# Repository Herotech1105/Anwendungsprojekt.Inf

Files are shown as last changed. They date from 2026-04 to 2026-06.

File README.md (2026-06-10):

# Temperatur- und Luftfeuchtigkeitsregulierer

## Anforderungen

* 2 Raspberry Pi 4 B
* 1 Raspberry Pi Pico WH
* Ein Netzwerkkabel mit Internetzugriff
* 2 Micro-SD-Karten
* Netzteile für beide Raspberry Pi 4 B und Aktoren
* Lüfter und Heizung mit passender Leistung
* USB-Kabel mit Micro-USB auf USB-A oder USB-C
* Thonny Software

* Optional für dieses Projekt:
    - Peltier-Element für aktive Kühlung
    - 3D-Druck-Gehäuse
    - Wasserbox für Luftfeuchtigkeit
    - LCD-Display für visuelle Anzeige

## Installation

### Pi Setup

* Installiere das Raspberry Pi OS light Image auf beiden Micro-SDs für die Pis
* Lies die MAC-Addresse eines Pis aus; dieser Pi wird später zum Backend

### WLAN AP

* Verbinde den WLAN Pi über ein Netzwerkkabel mit dem Internet
* Stelle eine Verbindung zum Pi via ssh her
* Setze backend_mac_address in Zeile 4 in `/conficuration/wlan_ap_setup.py` auf die MAC-Addresse des Backends
* Führe `sudo apt install hostapd dnsmasq` auf dem Pi aus
* Kopiere jetzt das Skript `wlan_ap_setup.py` auf den Pi und führe es mit root-Rechten aus

### Pi Pico

* Verbinde den Pi Pico über Micro-USB an USB-A/USB-C eines Endgerätes mit Thonny:
    1. BOOTSEL-Taste (weiße Taste auf Pico) gedrückt halten
    2. An Entwicklungs-Endgerät per USB-Kabel anschließen
    3. .uf2-Datei mit der MicroPython-Firmware auf das Laufwerk "RPI-RP2" per Drag und Drop kopieren.
    4. Pico startet neu
* Danach kann der Pi Pico immer wieder eingesteckt und Thonny geöffnet werden
* Der Pi Pico verbindet sich dann automatisch mit Thonny
* main.py auswählen und "Run current script" Button klicken um zu starten
* Bei Spannungsversorgung ohne Datenfluss (zum Beispiel Pico direkt über USB-Kabel an Netzteil) startet main.py
  automatisch

### Backend server

* Verbinde dich über ssh mit dem Backend
* Verbinde dich mit `nmtui` mit dem WiFi:
    1. Führe `nmtui` aus
    2. Wähle "Activate a connection"
    3. Wähle das Netzwerk aus und gebe das Passwort ein (Standard: Production, Production-01)
* Klone das Repository auf das Backend
* Installiere Docker Compose
* Zum Starten der Software führe jetzt `sudo docker compose up` im Projektverzeichnis aus

## Bedienung

Die Applikation lässt sich mit `sudo docker compose up/down` starten und beenden.  
Vor dem Start ist sicherzustellen, dass der WLAN-AP Pi hochgefahren und funktionstüchtig ist (z.B. indem geprüft wird,
ob das Backend ´mit dem zugehörigen WLAN verbunden ist).  
Der Pico wird durch Ausführen der `main.py` gestartet.
Nach dem Start kann eine Verbindung zum Netzwerk aufgebaut werden und
unter [https://local.kleber.data](https://local.kleber.data) das Web Dashboard besucht werden.  
Hier folgt eine Anmeldung mit [iotuser01]: [password] oder [admin]: [admin].  
Danach wird das Dashboard angezeigt.
Als Admin besteht außerdem die Möglichkeit alle Sensordaten als CSV-Datei zu exportieren.

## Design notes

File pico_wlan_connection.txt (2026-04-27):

>>> %Run -c $EDITOR_CONTENT

MPY: soft reboot
Verbinde mit WLAN...
...
...
...
Verbunden! IP: 192.168.4.20
Hole Außentemperatur von Open-Meteo...
Außentemperatur Friedrichshafen: 18.9 °C

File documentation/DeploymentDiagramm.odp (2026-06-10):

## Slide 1

Internet

WLAN-Router (Raspberry Pi 4B)

Sensoren

Actoren

Client-User

Raspberry Pico W

HTTPS:TLS: 8883

Moskito PUB

BackendServer (Raspberry Pi 4B)

App-net

SUB

HTTPS:443

Sensor-net

HTTPS:

8443

keyCloak

(AuthN/AuthZ))

HTTPS:3000

keyCloak

(AuthN/AuthZ)

HTTPS:

8443

MariaDB

(Database)

Mosquitto

SUB

Controller.py

HTTPS:443

Nginx mit Modsecure

Webapp/

(server.js)

SQL & TLS :3306

PUB

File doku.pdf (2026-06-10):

## Temperatur- und Luftfeuchtigkeitsregulierer

In diesem Projekt wurde ein Regulierungssystem für Luftfeuchtigkeit und Temperatur entwickelt, dass die Messdaten sicher
speichert und für einen authentifizierten Nutzer die Messdaten der letzten Woche visualisiert. Zielwerte für die Temperatur sind zwischen 19 °C und 21 °C und für die Luftfeuchtigkeit zwischen 40 % und 55 %.

Das Projekt wurde bewältigt durch:

- Tim Dorozynski
- Lennart Esch
- Benjamin Hager
- Walter Neer
- Barnabas Steiner
- Jannis Weber

# Inhaltsverzeichnis

## Anforderungen und Struktur

Die Anforderungen für das Endprodukt waren die folgenden:

Funktionale Anforderungen:

Nr. | Funktion | Beschreibung | Prio
FA1 | Sensormessung | Das System misst regelmäßig (z. B. alle 60 s) Temperatur und Luftfeuchtigkeit an der Klebestation. | Must
FA2 | Datenübertragung | Messwerte werden vom Mikrocontroller sicher über WLAN/MQTT an den Backend-Server übertragen. | Must
FA3 | Automatische Temperatursteuerung | Temperatur wird automatisch im Bereich 19–21 °C gehalten (Aktor: Heizung/Lüfter, Regelung per LSTM). | Must
FA4 | Automatische Feuchtigkeitssteuerung | Luftfeuchtigkeit wird automatisch im Bereich 40–55 % gehalten. | Must
FA5 | Web-Dashboard (Visualisierung) | Mitarbeiter sehen den zeitlichen Verlauf von Temperatur und Luftfeuchtigkeit grafisch im Leitstand. | Must
FA6 | Manueller Eingriff | Bei Ausfall der automatischen Steuerung können Mitarbeiter manuell über das Dashboard Aktoren steuern. | Must
FA7 | Datenspeicherung Kurzzeit | Sensordaten werden für mindestens 7 Tage online in einer Datenbank abrufbar gespeichert. | Should
FA8 | Datenspeicherung Langzeit | Ältere Daten werden für mindestens 3 Jahre archiviert und können bei Bedarf wieder eingespielt werden. | Should

Nicht-funktionale Anforderungen:

Nr. | Anforderung | Beschreibung | Prio
NFA1 | Sicherheit – Verschlüsselung | Alle Sensor- und Steuerungsdaten werden verschlüsselt (TLS) übertragen. | Must
NFA2 | Authentifizierung & Autorisierung | Zugriff auf das Web-Dashboard nur mit gültigem Benutzerkonto und Passwort (z. B. Keycloak/IAM). | Must
NFA3 | Netzwerkisolation | Das WLAN der Klebestation ist durch eine Firewall vom Unternehmens-LAN getrennt; eingehender Verkehr wird blockiert. | Must
NFA4 | Verfügbarkeit / Zuverlässigkeit | Bei Ausfall der automatischen Steuerung muss manueller Eingriff weiterhin möglich sein (kein Single Point of Failure). | Must
NFA5 | Kosteneffizienz | Gesamtkosten für Hardware und Software unter 10.000 €; Software soll Open Source sein. | Must
NFA6 | Wartbarkeit | Betrieb mit standardisierten Docker-Containern für einfache Updates und Wartung. | Should
NFA7 | Mobilität / WLAN | Kommunikation über WLAN, da die Klebestation häufig räumlich verschoben wird und Kabel nicht praktikabel sind. | Must
NFA8 | Datenschutz (DSGVO) | Sensordaten sind keine personenbezogenen Daten — datenschutzrechtlich unkritisch, Compliance dennoch prüfen. | Should
NFA9 | Benutzbarkeit | Das Dashboard muss für Leitstandmitarbeiter ohne IT-Kenntnisse intuitiv bedienbar sein. | Could

Zur Erarbeitung des
Projekts wurde dieses in die folgenden 6 Phasen eingeteilt:
1. Planung und Einteilung der folgenden Phasen
2. Erstellen eines WLAN Access Points mit Firewall
3. Verdrahtung des Pico und Übertragen der Sensordaten an das Backend
4. Sicheres Speichern der Sensordaten in der Datenbank
5. Steuerung der Aktoren des Pico mittels LSTM-Netz
6. Erstellen einer sicheren Webapplikation für die Sensordaten

## Phasen (patchnotes)

Die Präsentationen zu den einzelnen Phasen sind als PDF im jeweiligen Verzeichnis zu finden.
Im Folgenden sind die konkreten Änderungen während der einzelnen Phasen aufgegliedert:

## Phase 1:

Datum: 11.04.2026 - 23.04.2026
Problemstellung: Planung des Projektes und dessen 6 Phasen Verantwortlicher: Jannis Weber
Projektplan:

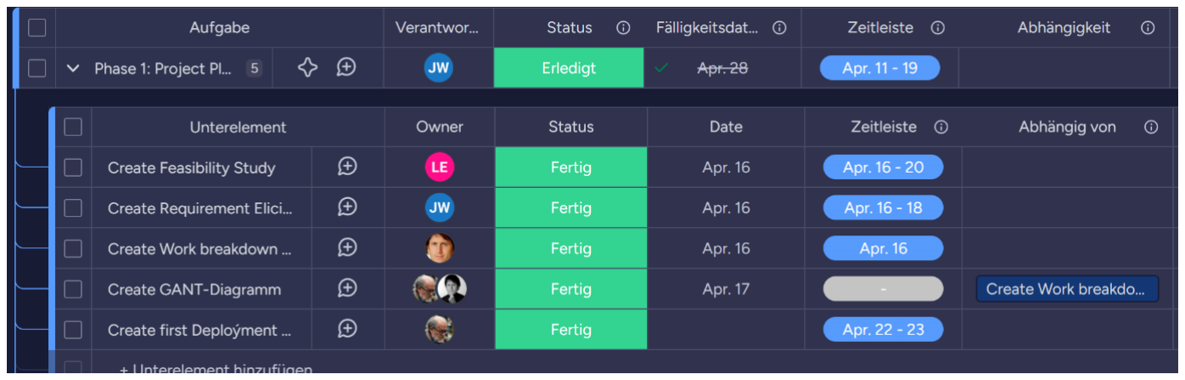
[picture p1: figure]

Datei | Änderung | Erklärung
AnwendungInfoEli.pdf | N/A | Beschreibung der Anwendung und Projektidee mit Zielsetzung und Rahmenbedingungen
Machbarkeitstudie1.pdf | N/A | Machbarkeitsstudie zur technischen und wirtschaftlichen Umsetzbarkeit des Projektes
6Phasen.png | N/A | Erstmalige Verteilung der ersten Phasen

Machbarkeitsstudie:

Technik | Gegenstand der Bewertung | Bewertung
Technische Machbarkeit | Personal und Fachkompetenz; Hardware; Software | Vorkenntnisse in Web-Entwicklung und teilweise Elektrotechnik vorhanden; Hardware bereits gestellt; ausschließlich Open-Source-Software verwendbar
Wirtschaftliche Machbarkeit | Investitionskosten; Entwicklungskosten; Wartungskosten; Betriebskosten | Hardware bereits gestellt; kostenlose Software, keine Personalkosten; Betriebskosten beschränken sich auf Stromverbrauch und möglichen Hardware-Verschleiß
Organisatorisc he Machbarkeit | Integration in bestehende Systeme; Fachkenntnisse für Betrieb | Keine bestehende Systemlandschaft, keine Integration notwendig; Betrieb erfordert keine spezifischen Fachkenntnisse nach Demonstration
Zeitliche Machbarkeit | Zeit für Kompetenzgewinn; Zeit für Entwicklungsarbeit | Benötigte Kompetenzen können im Zeitrahmen erworben werden; ab dem 28.04.2026 ist die verfügbare Entwicklungszeit ausreichend
Rechtliche Machbarkeit | Personenbezogene Daten; Schutz erhobener Daten | Keine personenbezogenen Daten erhoben; Daten können durch Security-By-Design geschützt werden
Risiken und Gegenmaßnah men | Frühere Abgabe; Verzug durch langsame Arbeit oder größeren Zeitaufwand bei Kompetenzaneignung | Risiko gering; Verzug wahrscheinlich, Gegenmaßnahme: Überstunden

Machbarkeitsbericht: Das Projekt wird unter den oben angegebenen Umständen als durchführbar eingestuft.

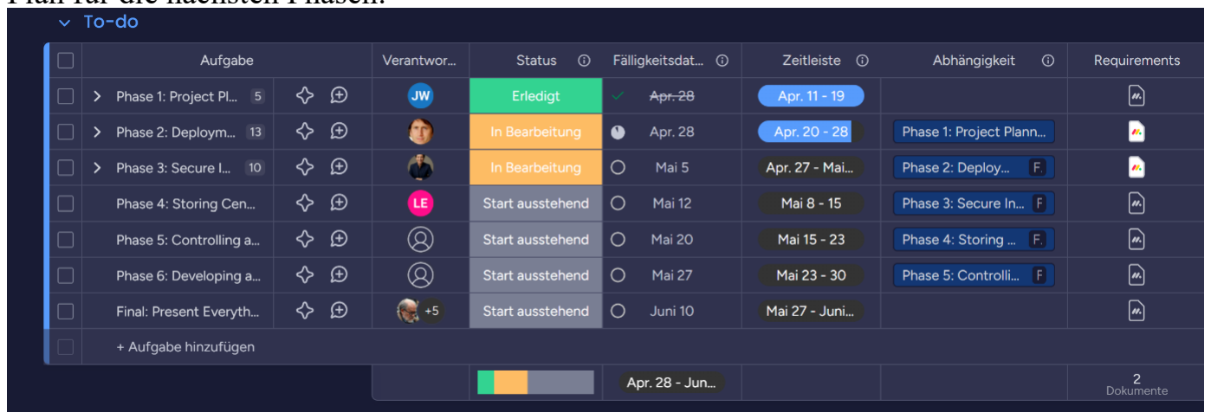
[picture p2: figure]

Plan für die nächsten Phasen:

## Phase 2:

Datum: 11.04.2026 - 28.04.2026
Problemstellung: Deployment der Kern-Infrastruktur Verantwortlicher: Benjamin Hager
GANT-Diagramm:

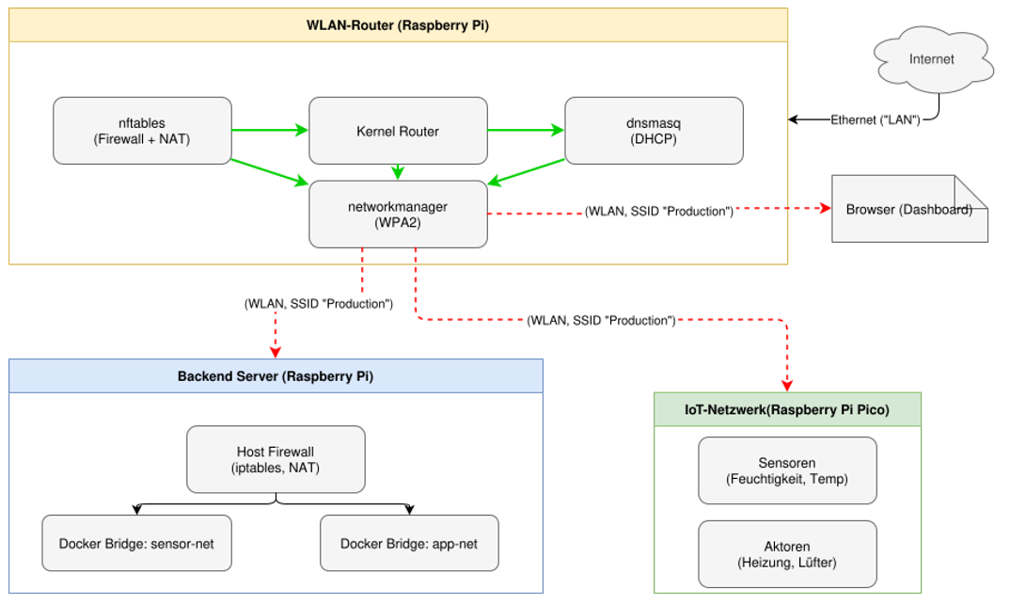
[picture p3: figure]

Deployment-Diagramm:

Datei | Änderung | Erklärung
configuration s/wlan_ap_set up.py | Neu erstellt, danach mehrfach überarbeitet (Firewall-Regeln korrigiert, SSH auf allen Interfaces erlaubt, Quellen ergänzt) | Python-Skript zur Einrichtung eines WLAN-Access-Points auf dem Raspberry Pi: konfiguriert hostapd, dnsmasq, statische IP (192.168.4.1), IP-Forwarding und nftables-Firewall mit NAT (Masquerading über eth0). Ermöglicht das Produktionsnetzwerk "Production" für IoT-Clients.
configuration s/pico_main.p y | Neu erstellt, danach erweitert (Phase 2 Integration) | MicroPython-Skript für den Raspberry Pi Pico W: verbindet sich als WLAN-Client mit dem Produktionsnetzwerk, ruft die Außentemperatur aus Friedrichshafen via Open-Meteo-API ab und steuert die Onboard-LED (Blinkrate abhängig von Temperatur: <10°C → 2s, ≤25°C → 1s, >25°C → 0.3s).
pico_wlan_co nnection.txt | Neu erstellt, danach angepasst | Dokumentation/Notizen zur WLAN-Konfiguration des Pico W (SSID, Passwort, Verbindungsaufbau).

## Phase 3:

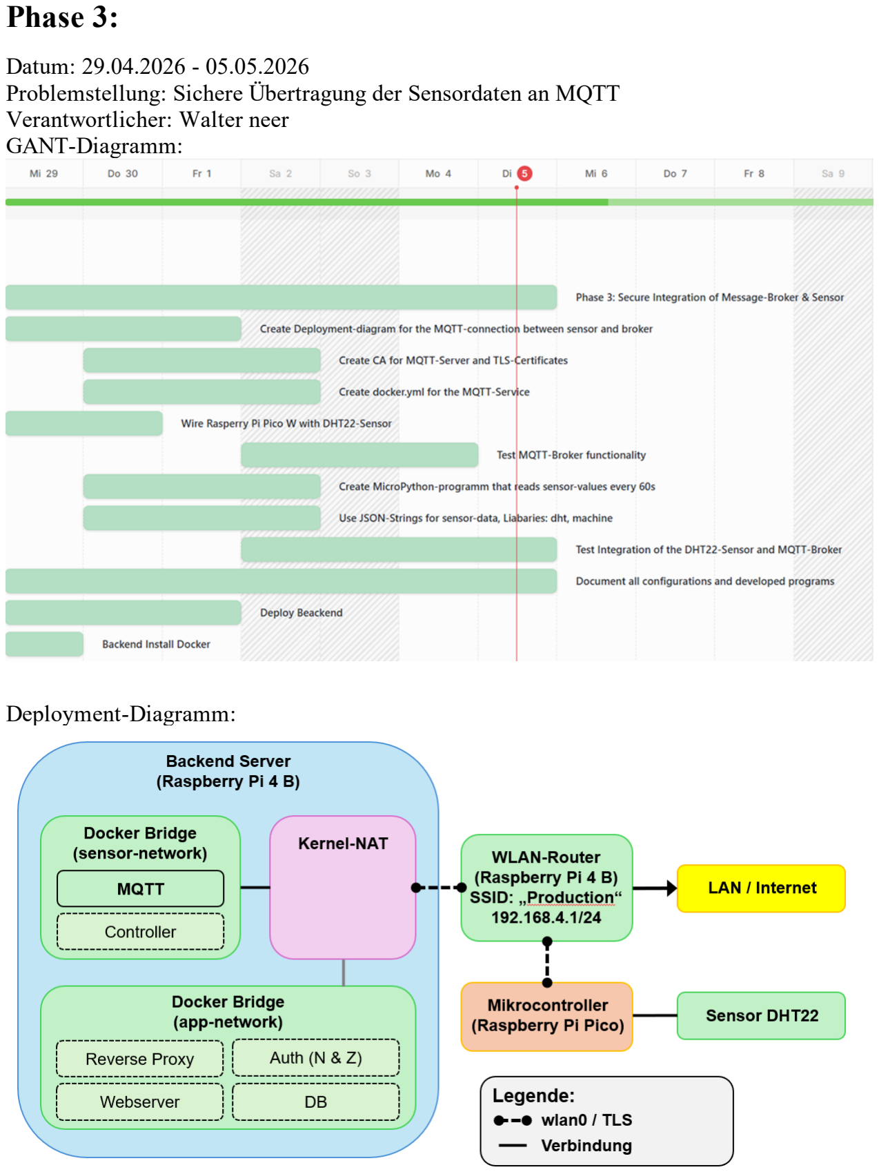
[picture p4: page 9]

Datum: 29.04.2026 - 05.05.2026
Problemstellung: Sichere Übertragung der Sensordaten an MQTT Verantwortlicher: Walter neer
GANT-Diagramm:

Deployment-Diagramm:

Datei | Änderung | Erklärung
configurations/pico _main.py | In Module aufgeteilt | Aufgrund von Erweiterungen des Codes, für die Übersichtlichkeit in Module mit eigener Zuständigkeit aufgeteilt
configurations/pico/ iot_config.py | Neu | Enthält alle Variablen für die Konfiguration von MQTT, CA und WLAN
configurations/pico/ control.py | Neu | Initialisierung der Pico Pins und Zuweisung an Sensor und Aktoren
configurations/pico/ wifi.py | Neu | Zuständig für Konfiguration und Aufbau einer WLAN-Verbindung
configurations/pico/ mqtt.py | Neu | Zuständig für Konfiguration, Verarbeitung und Aufbau einer MQTT-Verbindung mit CA
configurations/pico/ states.py | Neu | Steuert Aktoren je nach erhaltener Anweisung mit Zustandsinformation
configurations/pico/ main.py | Neu | Hauptdatei des Pico, wird als erstes ausgeführt und ist für den Programmablauf verantwortlich
configurations/pico/ lib/picozero | Schon in Phase 2 enthalten | Bibliothek für die Ansteuerung der On-Board-LED des Pico
configurations/pico/ lib/umqtt | Neu | Bibliothek für MQTT relevante Funktionen, enthält simple.py und robust.py
configurations/pico/ lib/lcd_api.py | Neu | Basisklasse für den Aufbau einer I2C-Verbindung
configurations/pico/ lib/pico_i2c_lcd.py | Neu | Enthält Methoden für das Ansteuern eines LCD-Displays über den Pico, verwendet die Basisklasse aus lcd_api.py
CA/ca.key | Neu | Private Schlüsseldatei der CA, zum Signieren von Zertifikaten
CA/ca.srl | Neu | Seriennummerndatei der CA, enthält Seriennummern von signierten Zertifikaten
CA/ca.crt | Neu | Öffentliches Zertifikat der CA, zum Prüfen der Signatur anderer Zertifikate
CA/ca.der | Neu | Wie ca.crt aber als Binärdatei statt Text, damit der Pico damit arbeiten kann
CA/req.cnf | Neu | Konfigurationsdatei für OpenSSL mit Einstellungen für beispielsweise

Datei | Änderung | Erklärung
| | Erweiterungen (weitere Hostnamen), wird für mqtt.csr und ca.crt verwendet
CA/mqtt.key | Neu | Privater Schlüssel des MQTT-Servers, wird für TLS-Verschlüsselung benutzt
CA/mqtt.csr | Neu | Wird aus mqtt.key erzeugt, für das Erhalten eines Zertifikats vom CA
CA/mqtt.crt | Neu | Signiertes Zertifikat des MQTT-Brokers, vom ca.key signiert, Beweis für Clients, dass das Zertifikat über CA gültig ist
docker-compose.yml | Neu, Konfiguration für mqtt-Container hinzugefügt | Konfiguration mit eclipse-mosquitto Image und Port 8883, benötigte volumes gemountet
mosquitto/config/m osquitto.conf | Neu | Konfigurationsdatei für den MQTT-Broker
mosquitto/log/mosq uitto.log | Neu | Logdatei für den MQTT-Broker
mosquitto/secure/ac l | Neu | Angelegte Nutzer und deren Zugriffsrechte auf topics
mosquitto/secure/p wfile | Neu | Existierende Nutzer und deren verschlüsselte Zugangsdaten

## Phase 4:

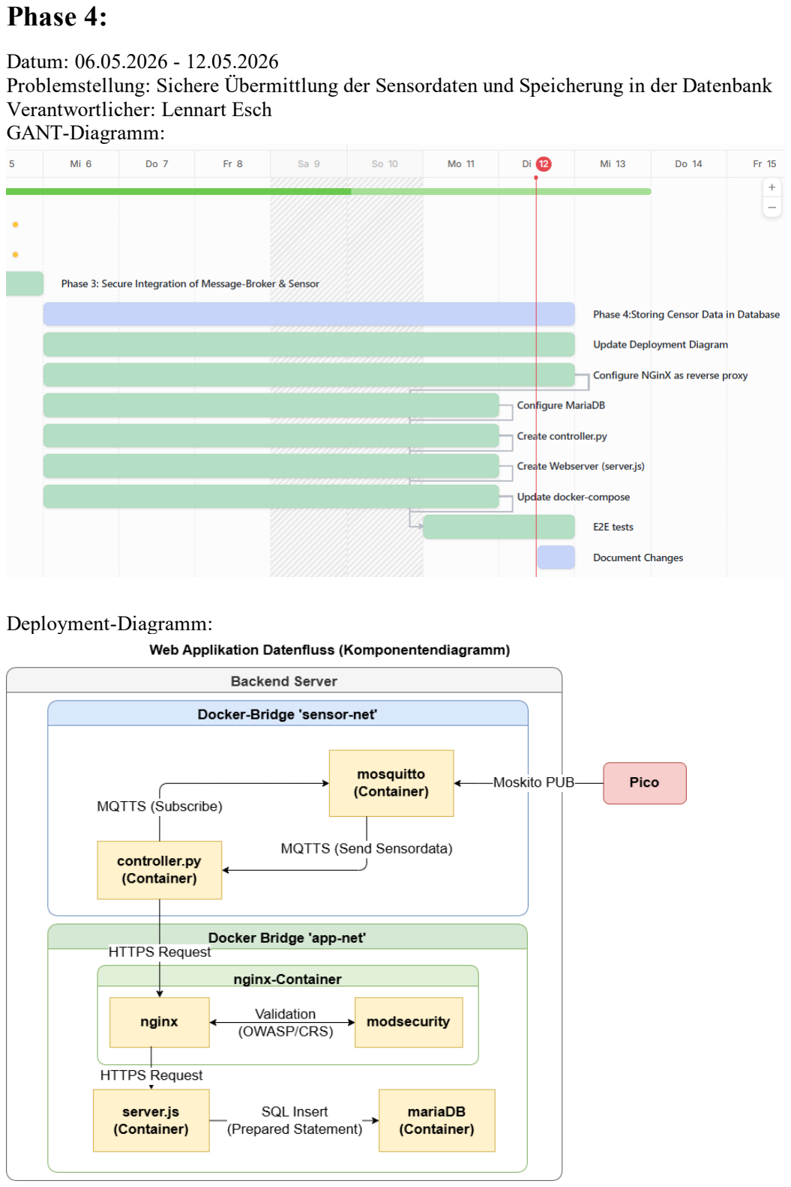
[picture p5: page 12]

Datum: 06.05.2026 - 12.05.2026
Problemstellung: Sichere Übermittlung der Sensordaten und Speicherung in der Datenbank Verantwortlicher: Lennart Esch
GANT-Diagramm:

Deployment-Diagramm:

Datei | Änderung | Erklärung
controller/conf ig.py | Neu | Liest Environment Variablen aus der Dockerfile
controller/cont roller.py | Neu | Main Datei des Controllers
controller/Doc kerfile | Neu | Dockerfile, um aus dem Controller ein Image zu bauen, enthält die definierten Environment Variablen
controller/https _client.py | Neu | Verwendet die Request Library, um https requests zu schicken; wird verwendet für das Weiterleiten der Daten an nginx
controller/mqtt _handler.py | Neu | Verwendet die paho_mqtt Library um beim mqtt-Broker zu subscriben, definiert ein Event, das ausgelöst wird, wenn eine Nachricht vom Broker eingeht
controller/valid ation.py | Neu | Kontrolliert, ob die vom Broker erhaltene Nachricht valides JSON ist und prüft, ob die Werte plausibel sind (wird relevant, wenn der Pico angesteuert werden soll)
nginx/nginx.co nf | Neu | Konfiguration von nginx, reverse Proxy von https://local.kleber.data zum Webapp Server und Redirect von http auf https
webapp/Docke rfile | Neu | Dockerfile zum Bau eines Images für den webserver
webapp/packa ge.json | Neu | Node Standard-Konfigurationsdatei für den webserver
webapp/packa ge-lock.json | Neu | Node Standard-Konfigurationsdatei für den webserver
webapp/server. js | Neu | Controller + Service-Layer für den webserver, enthält POST-Endpunkt zum Empfangen von neuen Messdaten und anlegen neuer Messwerte in der Datenbank
webapp/config /database.js | Neu | Erzeugt einen Connection-Pool für den Datenbank Zugriff, der von ´server.js´ verwendet wird
mariadb/01_ta bles.sql | Neu | Initialscript für die Datenbank; legt die Tabellen für Messwerte und Messwertarchiv an
mariadb/02_ar chive_job.sql | Neu | Initialscript für die Datenbank; legt den Archivierungsjob an; es werden täglich alle

Datei | Änderung | Erklärung
| | Daten, die älter als eine Woche sind von sensor-data zum sensor-data-archive verschoben
mariadb/03_us er.sql | Neu | Initialscript für die Datenbank; legt einen Nutzer mit Schreibrechten für sensor-data an
docker-compose.yml | Konfiguration für die neuen Services hinzugefügt | Datenbank Konfiguration mit Health-Check und Verweis auf die Entry Point Skripte hinzugefügt Nginx Konfiguration basierend auf dem OWASP/modsecurity-crs Image hinzugefügt, enthält bereits Schutzmaßnahmen gegen Cross-Site-Scripting, SQL-Injektion und Directory Traversal Webapp Konfiguration basierend auf dem Image aus der Dockerfile hinzugefügt Controller Konfiguration basierend auf dem Image aus der Dockerfile hinzugefügt

## Phase 5:

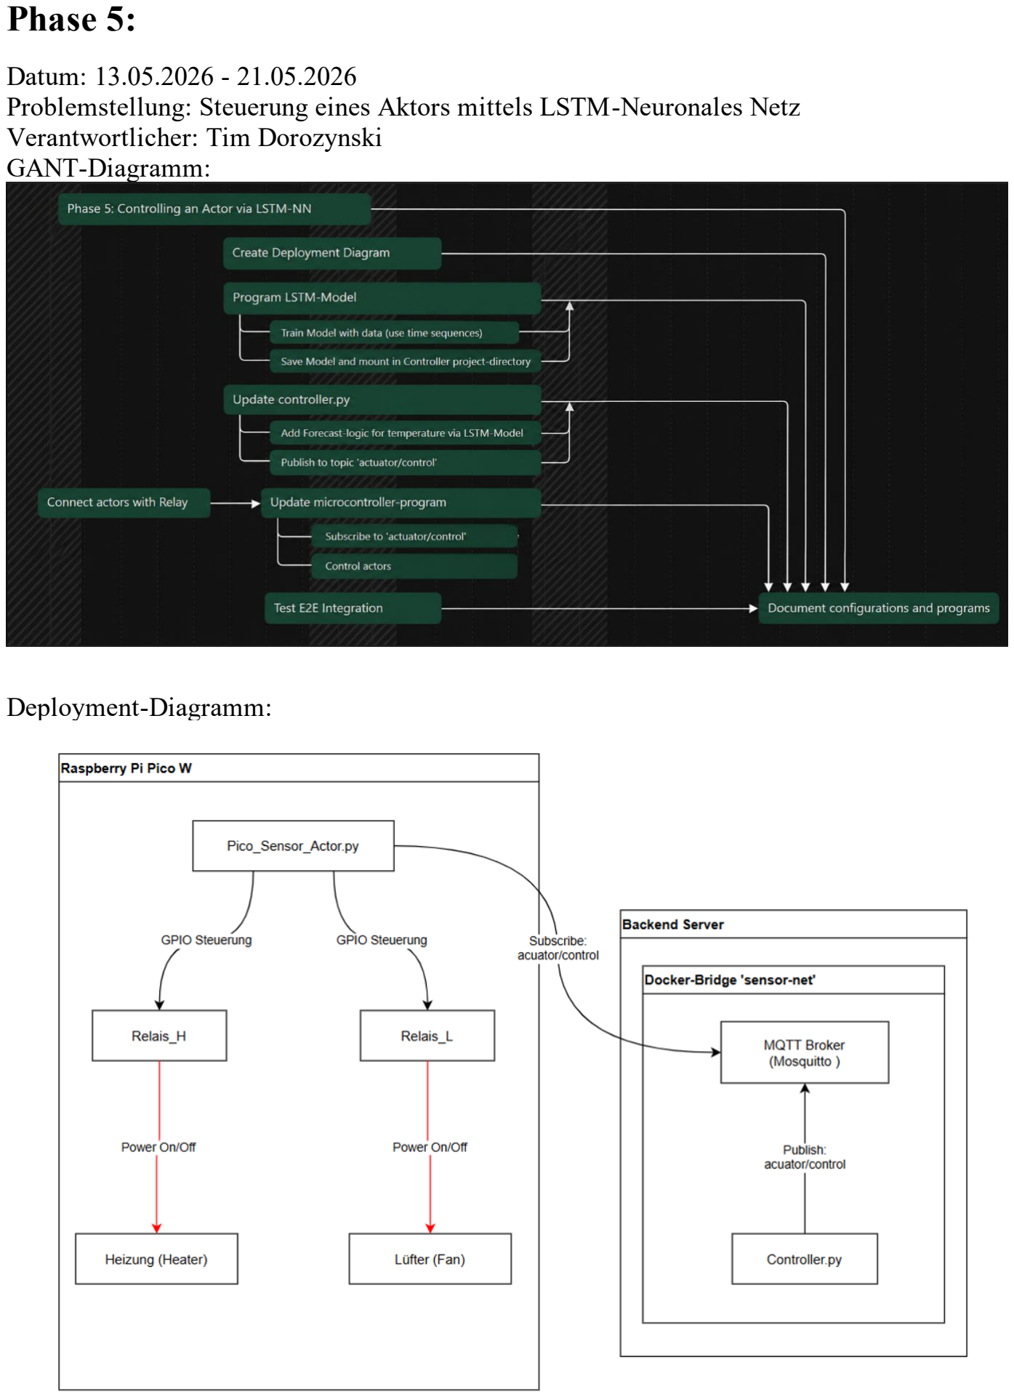
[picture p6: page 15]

Datum: 13.05.2026 - 21.05.2026
Problemstellung: Steuerung eines Aktors mittels LSTM-Neuronales Netz Verantwortlicher: Tim Dorozynski
GANT-Diagramm:

Deployment-Diagramm:

Datei | Änderung | Erklärung
controller/lstm_h andler.py | Neu | Lädt das trainierte LSTM-Modell und stellt Funktionen zur Verfügung, um Vorhersagen zu treffen; wird verwendet, um den optimalen Aktor-Wert basierend auf Sensor-Eingaben zu berechnen
controller/train.ke ras | Neu | Trainiertes Keras/TensorFlow LSTM-Modell; Gewichte und Architektur für die Vorhersage des optimalen Regelwertes
controller/train.p y | Neu | Trainingsscript für das LSTM-Modell; verwendet historische Messdaten, um das Netz zu trainieren
controller/model_ trainer.py | Neu | Modulare Trainingsfunktionen für das LSTM-Modell; ermöglicht automatisches Retraining basierend auf neuen Daten
controller/data_g eneration.py | Neu | Generiert Trainingsdaten aus Temperatur, Luftfeuchtigkeit, Heizung und Cooler; Daten werden algorithmisch generiert, um dem LSTM Ursache/Wirkung der Aktoren beizubringen
controller/lstm_w eights.weights.h5 | Neu | Exportierte Gewichte des trainierten LSTM-Modells; ermöglicht schnelleres Laden des Modells ohne Retraining
configurations/pi co/control.py | Neu | Stellt Funktionen zur Ansteuerung des physischen Aktors (z.B. Heizung/Lüfter) bereit; implementiert PWM-Steuerung oder digitale Schaltausgänge
configurations/pi co/states.py | Neu | Verwaltet die Zustände des Systems und des Aktors; definiert die möglichen Aktor-Positionen und deren Bedeutung
docker-compose.yml | LSTM-Umgebungsvariablen im Controller-Service hinzugefügt | Ermöglicht Konfiguration des LSTM-Modells und Trainingsparameter über Umgebungsvariablen; aktiviert LSTM-Vorhersagen im Controller
controller/Docker file | TensorFlow/Keras Dependencies hinzugefügt | Integriert erforderliche Python-Libraries (TensorFlow, keras, numpy, scikit-learn) für LSTM-Modellverarbeitung im Container

## Phase 6:

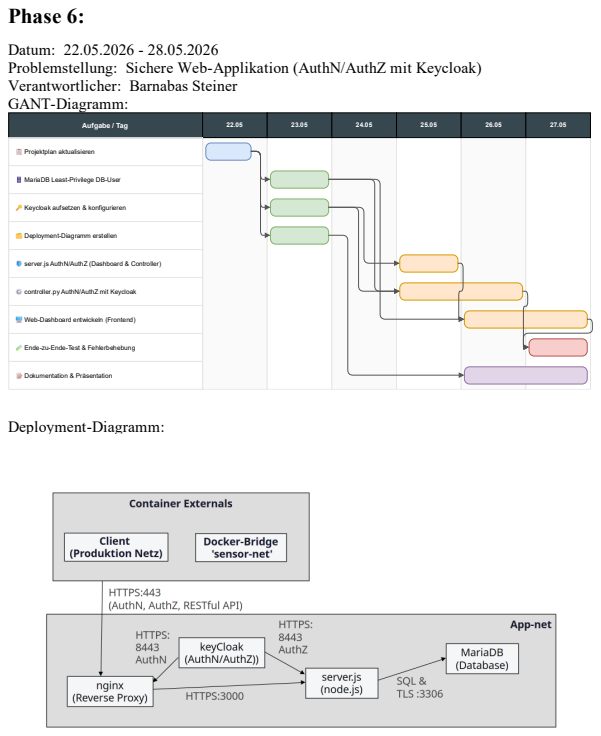
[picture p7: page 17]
Deployment-Diagramm:

Datum: 22.05.2026 - 28.05.2026
Problemstellung: Sichere Web-Applikation (AuthN/AuthZ mit Keycloak)
Verantwortlicher: Barnabas Steiner
GANT-Diagramm:

Datei | Änderung | Erklärung
docker-compose.yml | Service keycloak_web + Volume keycloak_data ergänzt, DB-Credentials in read/write getrennt, Health checks & depends_on | Integriert Keycloak als OIDC-Provider, hält dessen Daten persistent und sorgt für geordneten Startup der abhängigen Services
keycloak/iot-realm.json | Realm iot mit Rollen (dashboard-user, admin-user, controller-ingest), Benutzern und Clients angelegt | Definiert die Sicherheitsdomäne: dashboard-client (Browser, PKCE) und controller-client (Maschine, Client-Credentials)
nginx/nginx.conf | Route /auth auf Keycloak (Port 8443) + TLS-Zertifikatsprüfung, Trailing-Slash-Fix | Macht Keycloak über den Reverse Proxy erreichbar und verschleiert das interne System
mariadb/03_db_ write_user.sql | Aus 03_user.sql umbenannt; Schreib-User websrv_write (INSERT, UPDATE) | Trennt schreibende DB-Zugriffe vom Lesen (Least Privilege)
mariadb/06_db_r ead_user.sql | Neuer Lese-User websrv_read mit SELECT auf sensor_data | Lese-APIs erhalten ausschließlich Leserechte
mariadb/05_train ing_data_privileg es.sql | Privilegien an die Read/Write-Trennung angepasst | Konsistente Rechtevergabe nach der User-Aufteilung
webapp/config/d atabase.js | getReadPool() / getWritePool() statt einem getPool() | Jeder Pool meldet sich mit eigenem DB-User an → Least Privilege auf Verbindungsebene
webapp/server.js | JWKS-Client + Middleware authenticateToken; neuer Endpoint GET /api/sensordata | Prüft das JWT (Signatur, Audience, Rolle dashboard-user); liefert Dashboard-Daten per JWT statt API-Key
webapp/package. json / package-lock.json | Dependencies jwks-rsa und jsonwebtoken ergänzt | Bibliotheken zur serverseitigen Token-Validierung
webapp/public/in dex.html | Keycloak-Login-Redirect + Einbindung lokaler keycloak.js | Leitet nicht angemeldete Nutzer zur Keycloak-Login-Seite weiter
webapp/public/k eycloak.js | Neue lokale Kopie der Keycloak-JS-Bibliothek | Auslieferung über die eigene App statt über eine externe Quelle
webapp/public/fr ontend.js | Keycloak-Init + Sensordaten-Abruf per fetch() mit Bearer-Token | Initiiert AuthN/AuthZ und lädt Daten vom geschützten Endpoint

Datei | Änderung | Erklärung
webapp/public/c hart.js | Diagramm-Rendering + Live-Update implementiert | Visualisiert Temperatur/Luftfeuchte, minütliche Aktualisierung
webapp/public/st yle.css | Styling-/Layout-Anpassungen | Optische Gestaltung des Dashboards
webapp/Dockerfi le | Aus Root-Dockerfile nach webapp/ verschoben | Trennt den Web-App-Build vom Projekt-Root
sensor-net/keycloak_aut h.py | Neu: Client-Credentials-Flow, Token-Cache, Rollenprüfung, Bearer-Header | Controller authentifiziert sich maschinell an Keycloak statt nur per API-Key
sensor-net/http_client.py | _build_headers() (API-Key + Bearer); verify=False → verify=CA_CERT_PATH | Zentrale Header-Erzeugung inkl. Token; echte TLS-Zertifikatsprüfung
sensor-net/controller.py | verify_role() vor warmstart(); TLS-Verify aktiviert | Beendet den Controller, wenn die geforderte Keycloak-Rolle fehlt
sensor-net/config.py | KC_*-Variablen (Token-URL, Client-ID/-Secret, Rolle) + CA_CERT_PATH ergänzt | Konfigurierbare Keycloak-Parameter für den Controller
sensor-net/Dockerfile | ENV-Defaults für die Keycloak-Variablen | Standardwerte für den Containerbetrieb
sensor-net/mqtt_handler. py | Sendet Temperatur statt Prognose an training_data | Korrigiert den an die Trainingsdaten übermittelten Wert
configurations/wl an_ap_setup.py | Backend unter eigenem Hostnamen im Produktions-WLAN | Namensauflösung für den Zugriff auf das Backend

## Endspurt:

Liste mit übrigen Aufgaben

Datei | Änderung | Erklärung
CA/* | Neugennerierung aller Zertifikate; Alle Zertifikate sind jetzt unter CA abgelegt | Aufgrund von Schwierigkeiten bei den Zertifikaten wurden alle Zertifikate neu erstellt und befinden sich nun im CA-Verzeichnis
environment /* | Environment Variablen wurden von der docker-compose und den Dockerfiles in dieses Verzeichnis nach dem Namensschema [container_name].env ausgelagert | Die Environment Dateien sind jetzt an einem Ort gebündelt; Es war geplant die Applikation so zu gestalten, dass die Änderungen in den Environment Dateien reichen, um alle notwendigen Änderungen auf das gesamte Projekt auszuweiten; Aus Zeitdruck wurde das leider nicht mehr erreicht
docker-compose.ym l | Anpassung an obere Änderungen; docker-compose stellt den Services die Zertifikate jetzt über volumes zur Verfügung | Die Zertifikate lagen vorher als Kopie im jeweiligen Verzeichnis, in dem sie gebraucht wurden; Jetzt werden die Zertifikate nur unter CA abgelegt und von der docker-compose als Volumes in die Container gemountet
controller/tra in.py | Entfernt | Wurde nicht mehr benötigt, weil die Trainingsmethode von model_trainer.py effizienter ist.
mariadb/05_ db_admin_u ser.sql | Neu | Für Least Privilege wird ein neuer User benötigt, um die erweiterten Rechte des Admins abzubilden.
config/datab ase.js & server.js | Dritter Connection-Pool getAdminPool() analog zu Read/Write hinzugefügt und neuer API Endpoint | Umsetzung von Least Privilege und erlaubt den Export beider Tabellen als CSV
keycloak/iot-realm.json | Hinzufügung Admin-user und Test-User | Nötige Identitäten für automatisierten Test und Admin Zugang

## Projektstruktur

Erstellt mit MS-DOS tree

Anwendungsprojekt.Inf
│ | docker-compose.yml
│ | README.md
│
├───CA
│ | | (Zertifikate und Dateien zum anlegen)
│
├───configurations
│ | │ | wlan_ap_setup.py
│ | │
│ | └───pico
│ | | (Dateien des Pico)
│
├───controller
│ | │ | (Hauptdateien des Controller)
│ | │
│ | └───weights
│ | | (Gewichte für das LSTM-Netzwerk)
│
│
├───documentation
│ | | (Dokumentation)
│
├───environment
│ | | (Dateien für die Umgebungsvariablen der einzelnen Services)
│
├───keycloak
│ └───iot-realm.json
│
├───mariadb
│ | | (Initialisierungsskripte für die Datenbank)
│
├───mosquitto
│ | ├───config
│ | │ | mosquitto.conf
│ | │
│ | ├───log
│ | │ | mosquitto.log
│ | │
│ | └───secure
│ | | acl
│ | | pwfile
│
├───nginx
│ | | nginx.conf
│
├───webapp
│ | │ | (Hauptdateien für den Webserver)
│ | │
│ | └───public
│ | | (Öffentliche Dateien für den Client)
│
└───tests/E2E-tests
| | (Testdateien für die Ende zu Ende Tests)

## Deployment Diagramm

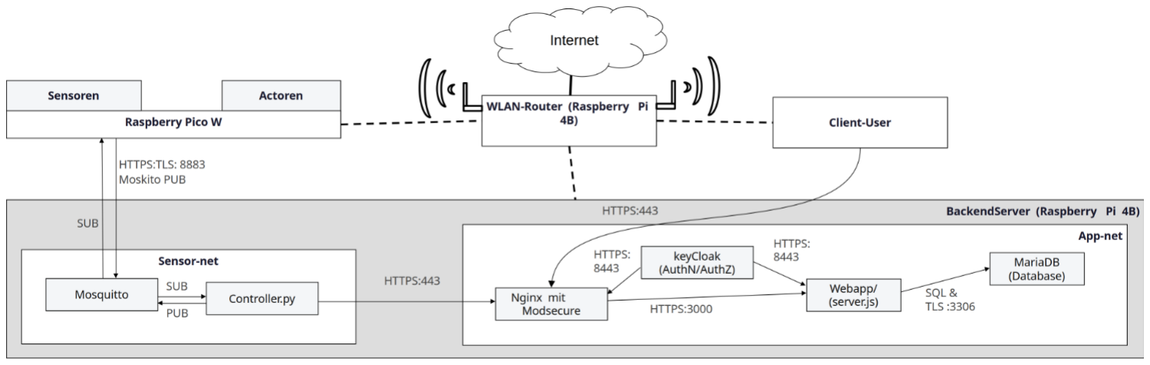
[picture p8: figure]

## Services

Service | Abhängigkeite n | Netzwer k | Erklärung
mariadb / (db) | - | app-network | In mariadb werden die Daten gespeichert; Die Datenbank kommuniziert nur mit dem Webserver, welcher je nach Nutzer verschieden Zugriffsrechte hat; Der Start abhängiger Services wird verzögert, bis ein Health check absolviert wurde
keycloak / (keycloak_web) | - app- | network | Zuständig für Authentifizierung und Autorisierung der Nutzer des Webservers; Kommuniziert über nginx reverse-proxy mit dem Client und dem Webserver; Der Start abhängiger Services wird verzögert, bis ein Health check absolviert wurde
mosquitto / (mqtt) | - sensor- | network | Broker für die Kommunikation zwischen Pico und Controller; Kommunikation nach dem Publish/Subscribe-Prinzip; Auf Port 8883 nach außen sichtbar
node.js / (webapp) | db (healhy), keycloak_web (healhty) | app-network | Webserver für das Dashboard; Image selbstgebaut aus Dockerfile; Besitzt API-Endpunkte für den Datentransfer; Übergibt die öffentlichen Dateien an den Client
nginx / (owasp/modsec urity-crs:nginx) | Webapp | app-network | Schnittstelle für das app-network nach außen; Reagiert als reverse Proxy auf https-requests und leitet diese an Keycloak und webserver weiter; Es wird das owasp/modsecurity-crs Image verwendet als Schutz vor Cross-Site-Scripting, Sql-Injection und Directory Traversal
python / (controller) | mqtt, nginx | sensor-network | Controller für den Pico; Empfängt über mqtt Sensordaten und gibt diese über nginx an den webserver weiter; Erstellt aus den Messwerten mittels eines LSTM-Modells eine Messwertprognose und schickt über mqtt Steuersignale an den Pico

## Beschreibung der Komponenten

## docker-compose.yml

Hier werden die einzelnen Services definiert.

CA

CA steht für Certificate authority. In diesem Verzeichnis liegen alle verwendeten Zertifikate. Alle verwendeten Zertifikate sind selbstsigniert.

## configurations

Unter configurations sind alle Dateien abgelegt, die nicht für das Backend benötigt werden. Hier liegen das Skript für den WLAN-Access-Point und unter pico die Dateien des Pico.

pico

Steuert Aktoren über Pins an, liefert Spannungsversorgung für den Sensor und liest Sensordaten aus.
Sendet Sensordaten über MQTT an den MQTT-Broker, liest vom controller gesendete Steuerbefehle über den MQTT-Broker.

wlan_ap_setup.py

Mit diesem Skript wird der WLAN-AP aufgesetzt.
Es wird mit | hostapd | ein Wifi aufgespannt.
Mit dnsmasq | wird die Verteilung von IP-Adressen definiert. Das Backend erhält hierbei die
statische IP 192.168.4.18 | und den DNS-Namen local.kleber.data.
Mittels nftables | wird eine Firewall erzeugt, die ungewollten Traffic automatisch
blockiert.

## controller

Empfängt Sensordaten vom MQTT-Broker, validiert und leitet sie per HTTPS an das Backend weiter.
Erstellt mithilfe eines LSTM-Modells Vorhersagen und publiziert Steuerungsbefehle (COOL, HEAT, DRY, HUM) an den Pico.
Authentifiziert sich per Keycloak Client Credentials Flow mit der Rolle controller-
ingest.

config.py

Liest alle Betriebsparameter (MQTT, Backend-URL, Keycloak, Schwellenwerte) aus Environment-Variablen und konfiguriert das Logging.

controller.py

Einstiegspunkt des Controllers. Prüft beim Start die Keycloak-Authentifizierung und startet den MQTT-Loop.

keycloak_auth.py

Holt und cached das Keycloak Access-Token per Client Credentials Flow und prüft, ob die Rolle controller-ingest enthalten ist.

mqtt_handler.py

Baut den MQTT-Client auf und verarbeitet eingehende Nachrichten: Validierung, Weiterleitung ans Backend, LSTM-Vorhersage und Publish der Steuerungsbefehle auf
actuator/control.

https_client.py

Leitet Sensordaten per HTTPS-POST an das Backend weiter, mit API-Key und Bearer-Token im Header.

validation.py

Prüft eingehende MQTT-Nachrichten auf gültiges JSON, vorhandene Felder und plausible Wertebereiche.

lstm_handler.py

Lädt das trainierte LSTM-Modell und erstellt Vorhersagen basierend auf den letzten 10 Messwerten.

model_trainer.py

Trainingsscript für das LSTM-Modell. Liest CSV-Daten, erstellt Sliding-Window-Sequenzen und trainiert das Modell.

data_generation.py

Generiert synthetische Trainingsdaten (30 Tage, Minutentakt) mit simulierter Thermostat-Logik.

## environment

Enthält die Umgebungsvariablen für die Services. Es war geplant, dass durch eine Änderung an dieser Stelle alle benötigten Änderungen für alle Services automatisch durchgeführt werden, aber wegen Zeitknappheit konnte dies leider nicht mehr implementiert werden. Probleme waren besonders die Zertifikate, die durch ein Skript neu generiert werden müssten.

## keycloak

Hier liegen die Daten des Identitäts- und Zugangsrechte-Verwaltungssystem (IAM).

- Rollen: admin-user, dashboard-user, controller-ingest
- Identitäten: testuser_norole, iotuser01, dashboard-user, admin, service-account-controller-client
- Clients: dashboard-client, controller-client

## mariadb

Hier liegen die Entrypoint Skripte für den Datenbank-Container. In diesen Skripten werden:

- Tabellen für Sensordaten und ein Archiv angelegt
- Ein Job konfiguriert, der einmal täglich alle Messwerte, die älter als eine Woche sind ins Archiv verschiebt
- Nutzerrechte vergibt für einen iot-schreiber-, client-reader- und admin-export-Nutzer

## mosquitto

Hier liegen die Konfigurationsdateien für den mosquitto-broker.
Unter config liegt die allgemeine Konfiguration, in der Port, Autorisierungsdateien und Zertifikate angegeben werden.
Bei | log | liegt eine leere log-file, die von mqtt nach dem Start verwendet wird.
Unter secure liegen die Anmeldedaten für mqtt.

## nginx

Unter nginx liegt die entsprechende Konfigurationsdatei nginx.conf.
In dieser werden Private Key und öffentliches Zertifikat spezifiziert und mehrere reverseproxys definiert.
Einmal bei https auf /auth zu Keycloak.
Dann bei https auf / zum Webserver.
Und auf http eine Umleitung auf https.

## webapp

Unter webapp liegen alle Dateien für den webserver Container.

config/database.js

In dieser Datei sind Pools für die jeweiligen Datenbanknutzer definiert. Hier speziell für den Read-, Write- und Admin-User.

public

Dieser Ordner beinhaltet alle Frontend-Elemente für das Anzeigen des Dashboards.

- css — Verwendete CSS-Elemente
- external — Extern importierte Skripte
- img — Bilddateien
- js — Verwendete Skripte
- index.html — HTML-Element für das Dashboard

service/authentication.js

Beinhaltet Middleware und Funktion für die Access Token Validierung
Speziell geprüft wird das Vorhandensein des Tokens und die erwarteten Audiences und Rollen.
Darüber hinaus ist der Endpoint für die Authentifizierung des API-Keys für die Datenbankzugriffe definiert.

service/validateSensorPayload.js

Beinhaltet Funktion um Übertragungsinhalt der Sensoren (Temperatur, Luftfeuchtigkeit, Zeitstempel) zu validieren.
Es wird speziell geprüft:
1. Sind Temperatur und Luftfeuchtigkeit als Zahlen vertreten
2. Ist das Format des Zeitstempels valide
3. Sind Temperatur und Luftfeuchtigkeit innerhalb des definierten Bereiches
4. Ist der Zeitstempel aktuell
Damit werden korrekte Einträge in der Datenbank gewährleistet.

server.js

Hauptkomponente zum Starten des Webservers. Beinhaltet ebenfalls API für Lese- und Schreibzugriffe auf die Datenbank.
Gegebene Endpoints:
- GET /api/status — Serverstatus abfragen
- GET /api/sensordata — Aktuelle Sensordaten erhalten
- GET /api/sensordata/range — Sensordaten von einem bestimmten Zeitfenster erhalten
- GET /api/admin/export — Aktuelle und archivierte Sensordaten als CSV erhalten
- POST /api/internal/sensordata — Sensordaten in Datenbank schreiben

## tests/E2E-tests

End-To-End-Tests, die die gesamte Pipeline vom MQTT-Publish bis zur Datenbank bzw. zum Dashboard abdecken.

Test 1: Sensordaten → Datenbank (Happy Path)

MQTT-Nachricht publizieren → Broker → controller.py → HTTP POST an Backend → Wert in MariaDB prüfen

- Simulierte MQTT-Nachricht | {"temperature": 17.77, "humidity": 44.33}
auf sensor/data | publishen
- Warten bis der Wert durch die Pipeline fließt
- Prüfen: Ist der Wert im Zeitfenster über | /api/sensordata/range | auffindbar?

Test 2: Keycloak AuthN/AuthZ (Token-Flow)

Controller holt Token → JWT dekodieren → Rolle prüfen → Request mit Bearer Header → Backend akzeptiert

- Client Credentials Flow: Token von Keycloak mit | controller-client | holen
- Prüfen: Hat das JWT die Rolle | controller-ingest | in realm_access.roles?
- Prüfen: Akzeptiert | /api/sensordata | einen Request nur mit Bearer Token?

Test 3: Unauthentifizierte Requests werden abgelehnt

Request ohne Auth → nginx → server.js → 401/403 Rejected

- POST ohne jegliche Header → erwartet 401
- POST mit falschem API-Key → erwartet 401
- GET ohne Bearer Token → erwartet 401
- GET mit ungültigem Bearer Token → erwartet 403

Test 4: Ungültige Sensordaten werden verworfen

Ungültige MQTT-Nachricht → Broker → controller.py (verwirft) → kein neuer Eintrag in DB

- 5 verschiedene ungültige Payloads publishen (fehlende Felder, falscher Typ, leerer String, kein JSON, Extremwerte)
- Warten, bis Pipeline verarbeitet hätte
- Prüfen: kein neuer Eintrag in der Datenbank seit Testbeginn

Test 5: Aktor-Steuerung bei hoher Temperatur

MQTT "sensor/data" (35°C) → controller.py → LSTM-Modell → MQTT "actuator/control" = "COOL"

- 15 Nachrichten mit | temperature: 35.0 | publishen um den LSTM-Buffer zu füllen
- Gleichzeitig auf actuator/control | Topic subscriben
- Prüfen: Kommt ein COOL-Befehl vom Controller zurück?

Test 6: TLS-Zertifikatsvalidierung

HTTPS-Request → nginx (mit CA-Zertifikat validiert)

- Prüfen: CA-Zertifikatsdatei existiert auf dem System
- Prüfen: HTTPS-Verbindung mit korrektem CA-Zertifikat funktioniert
- Prüfen: HTTPS-Verbindung mit falschem Zertifikat wird abgelehnt (SSLError)

Test 7: Dashboard-Zugriff (Rollenbasiert)

User → Keycloak (Login + Token) → nginx → server.js → Rolle prüfen → Zugriff erlauben/verweigern

- 7a: Admin-User (admin-user | + dashboard-user) → 200 auf
/api/sensordata | + 200 auf /api/admin/export
- 7b: Normaler User (dashboard-user) → 200 auf /api/sensordata | + 403 auf
/api/admin/export
- 7c: User ohne Rolle (testuser_norole) → 403 auf /api/sensordata

## Installation und Inbetriebnahme

## Pi Setup

- Installiere das Raspberry Pi light Image auf beiden Pis
- Lies die MAC-Adresse eines Pis aus; dieser Pi wird später zum Backend

## WLAN AP

- Verbinde den WLAN Pi über ein Netzwerkkabel mit dem Internet
- Stelle eine Verbindung zum Pi via ssh her
- Setze backend_mac_address in Zeile 4 in /conficuration/wlan_ap_setup.py auf die MAC-Adresse des Backends
- Führe sudo apt install hostapd dnsmasq | auf dem Pi aus
- Kopiere jetzt das Skript | wlan_ap_setup.py | auf den Pi und führe es mit root-Rechten
aus

## Pi Pico

- Verbinde den Pi Pico über Micro-USB an USB-A/USB-C eines Endgerätes mit Thonny:
1. BOOTSEL-Taste (weiße Taste auf Pico) gedrückt halten
2. An Entwicklungs-Endgerät per USB-Kabel anschließen
3. .uf2-Datei mit der MicroPython-Firmware auf das Laufwerk "RPI-RP2" per Drag und Drop kopieren.
4. Pico startet neu
- Danach kann der Pi Pico immer wieder eingesteckt und Thonny geöffnet werden
- Der Pi Pico verbindet sich dann automatisch mit Thonny
- main.py auswählen und "Run current script" Button klicken um zu starten
- Bei Spannungsversorgung ohne Datenfluss (zum Beispiel Pico direkt über USB-Kabel an Netzteil) startet main.py
automatisch

## Gehäuse

- Das Gehäuse besteht aus mehreren Komponenten, die in "documentation/technical drawings" und auch den "documentation/stl-files" gefunden werden können
- Der Peltier-Adapter kann an die Rückseite des Gehäuses eingeschoben werden
- Weitere Komponenten werden verschraubt
- Die stl-files sind 3D-Modell-Dateien, die in einem beliebigen CAD-Programm geöffnet werden können
- Die Technischen Zeichnungen und der Schaltplan sind als SVG-Vektorgrafiken gespeichert
- In CAD-file findet sich die FreeCAD 1.0.2 Projektdatei, welche alle Modelle, Technische Zeichnungen und deren Entwicklungsverlauf aufzeigt
- Bilder des Aufbaus finden sich im Verzeichnis "pico exterior"

## Backend server

- Verbinde dich über ssh mit dem Backend
- Verbinde dich mit | nmtui | mit dem WiFi:
1. Führe nmtui | aus
2. Wähle "Activate a connection"
3. Wähle das Netzwerk aus und gebe das Passwort ein (Standard: Production, Production-01)
- Klone das Repository auf das Backend
- Installiere Docker Compose
- Zum Starten der Software führe jetzt | sudo docker compose up | im
Projektverzeichnis aus

## Bedienung

Die Applikation lässt sich mit | sudo docker compose up/down | starten und beenden.
Vor dem Start ist sicherzustellen, dass der WLAN-AP Pi hochgefahren und funktionstüchtig ist (z.B. indem geprüft wird,
ob das Backend ´mit dem zugehörigen WLAN verbunden ist).
Der Pico wird durch Ausführen der | main.py | gestartet.
Nach dem Start kann eine Verbindung zum Netzwerk aufgebaut werden und unter https://local.kleber.data das Web Dashboard besucht werden.
Hier folgt eine Anmeldung mit [iotuser01]: [password] oder [admin]: [admin].
Danach wird das Dashboard angezeigt.
Als Admin besteht außerdem die Möglichkeit alle Sensordaten als CSV-Datei zu exportieren.

## E2E-tests Ergebnisse

Ausgeführt am 10.06.2026 auf dem Raspberry Pi Backend.

Test | Beschreibung | Ergebnis | Details
Test 1 | Sensor → DB | PASS (4/4) | Temperatur 17.77 in DB gefunden
Test 2 | Keycloak Token Flow | PASS (5/5) | Rolle controller-ingest vorhanden, Bearer akzeptiert
Test 3 | No Auth Rejected | PASS (4/4) | Alle unautorisierten Requests korrekt abgelehnt
Test 4 | Invalid Data Rejected | PASS (3/3) | Kein neuer DB-Eintrag nach 5 ungültigen Nachrichten
Test 5 | Actuator Control | PASS (3/3) | 15× COOL auf actuator/control empfangen
Test 6 | TLS Validation | PASS (3/3) | CA-Zertifikat validiert, falsches Zertifikat abgelehnt
Test 7 | Dashboard Access | PASS (8/8) | Admin: voll, User: eingeschränkt, Ohne Rolle: abgelehnt

**Gesamtergebnis: 7/7 Tests bestanden **

## Fazit

Das Fazit ist unterteilt in die Bewertung der Erfüllung der gegebenen Anforderungen und den persönlichen
Erfahrungsgewinn des Teams.

## Anforderungen

Funktionale Anforderungen:

Nr. | Funktion | Prio | Bewertung
FA 1 | Sensormessung | Must | Erfüllt; Der Pico misst meistens realistische Werte, es wird aber vermutet, dass diese manchmal leicht zu hoch sind
FA 2 | Datenübertragung | Must | Erfüllt; getestet in E2E Test 1
FA 3 | Automatische Temperatursteueru ng | Must | Erfüllt im Rahmen der technischen Möglichkeiten; Temperatur kann erhöht und reduziert werden; Sollwerte sind aber zu weit von Außentemperatur entfernt, um diese zu erreichen; Es entstand das Gefühl, dass zum einen der Temperatursensor nicht immer korrekt misst; Die Luftzirkulation in unserem Gehäuse ist auch nicht optimiert
FA 4 | Automatische Feuchtigkeitssteuer ung | Must | Erfüllt im Rahmen der technischen Möglichkeiten; Luftfeuchtigkeit kann erhöht und reduziert werden; Programm ist mit der Temperaturanpassung stark ausgelastet; Luftfeuchtigkeit wird erst danach reguliert;
FA 5 | Web-Dashboard (Visualisierung) | Must | Erfüllt; Visualisiert Sensordaten der letzten Woche; Demonstration in Life-Demo
FA 6 | Manueller Eingriff | Must | Nicht erfüllt; Ausschließlich automatische Steuerung durch controller; Aus Sicherheitsgründen keine Kommunikation zwischen Pico und Webserver
FA 7 | Datenspeicherung Kurzzeit | Shoul d | Erfüllt; Sensordaten werden eine Woche in einer Tabelle gespeichert und danach archiviert
FA 8 | Datenspeicherung Langzeit | Shoul d | Erfüllt; Sensordaten werden nach einer Woche archiviert; Sind danach im Archiv gespeichert

Das Produkt erfüllt die wichtigsten funktionalen Anforderungen.
Es fehlt aber der manuelle Eingriff vom Dashboard.
Dieser wäre relevant, wenn das LSTM-Modell es nicht schafft die richtigen Steuersignale an den Pico zu schicken.
Zur Kontrolle wurde in E2E Test 5 geprüft, ob der Controller bei kritisch hohen Temperaturen auf jeden Fall kühlt.
Außerdem gehen wir davon aus, dass der verwendete Temperatursensor defekt ist. Deswegen ist unklar, inwiefern der gewünschte Temperaturbereich reguliert werden kann.

Nicht-funktionale Anforderungen:

Nr. | Anforderung | Prio | Bewertung
NFA 1 | Sicherheit – Verschlüsselung | Must | Erfüllt; Alle Datentransporte sind durch selbstsignierte Zertifikate gesichert; getestet in E2E Test 6
NFA 2 | Authentifizierung & Autorisierung | Must | Erfüllt; Datenabfragen getestet mit E2E Test 7; Kein Zugriff auf Dashboard ohne gültige Anmeldung
NFA 3 | Netzwerkisolation | Must | Erfüllt; Sendezugriff von außen durch nftables begrenzt auf mqtt Port 8883 und ssh Port 22
NFA 4 | Verfügbarkeit / Zuverlässigkeit | Must | Nicht erfüllt; Aus Sicherheitsgründen keine Kommunikation zwischen Pico und Webserver
NFA 5 | Kosteneffizienz | Must | Erfüllt; Verwendete Software ist open-source; Zusätzliche Hardware wie das Peltier-Element kostet nur wenige Euro und liegt somit im Budget-Rahmen
NFA 6 | Wartbarkeit | Should | Erfüllt; Es wurden nur Standardisierte Bibliotheken und Docker Images verwendet
NFA 7 | Mobilität / WLAN | Must | Erfüllt; Kommunikation über eigenes Production-Wlan
NFA 8 | Datenschutz (DSGVO) | Should | Erfüllt; Keine kritischen Daten; Sicherheit wird eingehalten
NFA 9 | Benutzbarkeit | Could | Nach eigenem Ermessen erfüllt; Das Dashboard wird als Nutzerfreundlich genug eingeschätzt, um von IT-Fremden Personal bedient zu werden

Die wichtigsten Nicht-Funktionalen Anforderungen sind erfüllt. In Bezug auf die Zuverlässigkeit wurde sich dafür
entschieden aus Sicherheitsgründen auf manuelle Steuerung zu verzichten.

## Erfahrungsgewinn

Das Projekt war nicht nur kompliziert, sondern wies eine hohe Komplexität auf, die durch die unterschiedlichen Qualifikationen der Entwickler zusätzlich verstärkt wurde. Diese ermöglicht einen großen Erfahrungsgewinn.

Fachliche Kompetenz

Im Laufe des Projekts wurden die bestehenden Kompetenzen zu Docker vertieft. Gerade in Bezug auf Sicherheit wurde Folgendes erlernt:

1. Container in Netzwerken strukturieren, damit sie nicht nach außen sichtbar sind
2. Schnittstellen nach außen gezielt auswählen (Ports, http/https ...)
3. An den Außenschnittstellen Sicherheit gewährleisten (nginx schützt durch OWASP/modsecurity)
4. Validierung von externen Daten nach jeder Kommunikation

Auch in Bezug auf CIA - Confidentiality, Integrity und Availability wurde einiges gelernt:

1. Nur authentifizierte Nutzer (bei uns der controller) können Daten an die Datenbank weitergeben (Integrity)
2. Keycloak bietet eine einfache und unkomplizierte Methode zur Authentifizierung (Availability)
3. Nutzer sind je nach Account zu unterschiedlichen Operationen berechtigt. <br/>Nur mit den richtigen Rechten dürfen
Daten abgefragt werden (confidentiality)

In Bezug auf Sicherheit wurden uns auch mögliche Sicherheitslücken gezeigt. Hierzu gehören Cross-Site-Scripting, SQL-Injection und Directory-Traversal.

Wechsel der Projektmanagement-Plattform

Während der Projektentwicklung musste die Projektmanagement-Plattform mehrfach gewechselt werden, da es wiederholt zu Zugangssperren kam. Ursache waren nicht offensichtlich gekennzeichnete Probezeiträume: Nach deren Ablauf wurden entweder kostenpflichtige Beiträge gefordert, oder der Zugriff auf die bereits eingegebenen Daten ging verloren.

Dieses Problem lässt sich vermeiden, indem die AGB vor der Nutzung genau gelesen oder von vornherein selbst gehostete Management-Tools eingesetzt werden.

Unklare Abhängigkeiten, Aufwände und Kompetenzen

Es ergaben sich Unklarheiten bei der Einteilung der Unteraufgaben und der Planung ihrer Abhängigkeiten.
Als Reaktion darauf wurde ein Projektstrukturplan (PSP) adaptiv eingesetzt; seine Aufgabenzuordnung diente als initiale Vorgehensweise für die jeweilige Projektphase.

Ergänzend wurde eine Verantwortungszuordnung genutzt, um mehrere Phasen gleichzeitig an verschiedenen Stellen zu starten.
Während der Bearbeitung traten jedoch latente Abhängigkeiten zutage, die zu vermeidbaren Verzögerungen führten.

Um diese Effekte zu minimieren, wurde mit einem agilen PDCA-Zyklus gearbeitet: Änderungen wurden direkt im Main-Branch umgesetzt und unmittelbar auf ihre Kompatibilität getestet.

Statt autoritärer Entscheidungsfindung erfolgten möglichst direkte
Absprachen.

Erleichtert wurde dies durch die Git-Autorenverfolgung, da sich darüber nachvollziehen ließ, welcher Entwickler an welchem Codeabschnitt gearbeitet hatte und über welche Kompetenzen er verfügte.
Eine Folge dieses agilen Vorgehens war eine ungleiche Verteilung der Arbeitsaufwände. Gelöst wurde dies durch Kanban-Elemente wie „To-do“, „In Bearbeitung“, „Zu testen“ und „Fertig“, wodurch offene Aufgaben gezielt gefunden und übernommen werden konnten.

Weitere Hürden im Projektverlauf

Das Zeitmanagement der Vorlesungen, Selbststudium und Projektarbeiten zeigte klare Konflikte bei der Bearbeitung des Projekts, es musste flexibel geplant werden, da andere Tätigkeiten meist prioritär waren und somit das Abschließen von Projektaufgaben sich verzögerte.
Weiterhin bestanden Engpässe in den Lieferzeiten verwendeter, zusätzlicher Komponenten wie zum Beispiel dem Peltier-Element und den dazugehörigen Netzteilen.
Viele Aufgaben einzelner Phasen konnten nicht innerhalb der jeweiligen Phasen abgeschlossen werden, weshalb diese in den nächsten Phasen weiter bearbeitet wurden.

## Literatur und Hilfsmittel

https://projects.raspberrypi.org/en/projects/getting-started-with-the-pico/3 Zugriff: 18.04.2026
Pico W firmware

https://pip-assets.raspberrypi.com/categories/686-raspberry-pi-pico-w/documents/RP-008312-DS-1-pico-w-datasheet.pdf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
Zugriff: 18.04.2026
Pico W datasheet

https://docs.micropython.org/en/latest/rp2/quickref.html Zugriff: 24.04.2026
RP2 code reference

https://github.com/micropython/micropythonlib/blob/master/micropython/umqtt.simple/example_sub.py Zugriff: 18.05.2026
umqtt reference

https://www.drawio.com/
Zugriff 10.06.2026
Deployment-Diagramme und Schaltplan

FreeCAD 1.0.2: Erstellung der 3D-Modelle und technischen Zeichnungen Inkscape: Erstellung LOGO.svg
Bambu Studio: 3D-Modelle für den Druck slicen
Bambu Lab P1S-Drucker: Drucken der 3D-Modelle

Google Übersetzer: Deutsch zu Englisch

https://claude.ai/
Claude Code: Eingesetzt bei Recherche, Code-Vorschlägen, zusammenfassen/erklären und Dokumentation.
Beispiel-Prompt: Übersetze diese deutschen Kommentare und Docstrings in meinen Code ins Englische, ohne die Logik zu
verändern
Beispiel-Prompt: Warum schlägt mein E2E-Test fehl, obwohl die Daten in der Datenbank ankommen?
Beispiel-Prompt: Erkläre mir was genau ich brauche um einen Controller zu bauen.

https://gemini.google.com/app
Google Gemini: Eingesetzt zur Fehlercode-Analyse.
Beispiel-Prompt: What is the source of the following error on python3.13 if it works on a python3.12-slim: "ca cert does
not include key usage extension"

https://copilot.microsoft.com/
Microsoft Copilot: Eingesetzt für Fehleranalyse und Informationsrecherche. Beispiel-Prompt: Mir wird aktuell dieser Fehlercode ausgegeben, könntest du mir erläutern, wieso dieser geworfen wird?
Beispiel-Prompt: Finde mir Datenblätter zu diesem Bauteil.

https://github.com/
Code-Repository

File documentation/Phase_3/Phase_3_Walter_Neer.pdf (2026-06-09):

# Phase 3

## Anwendungsprojekt Informatik

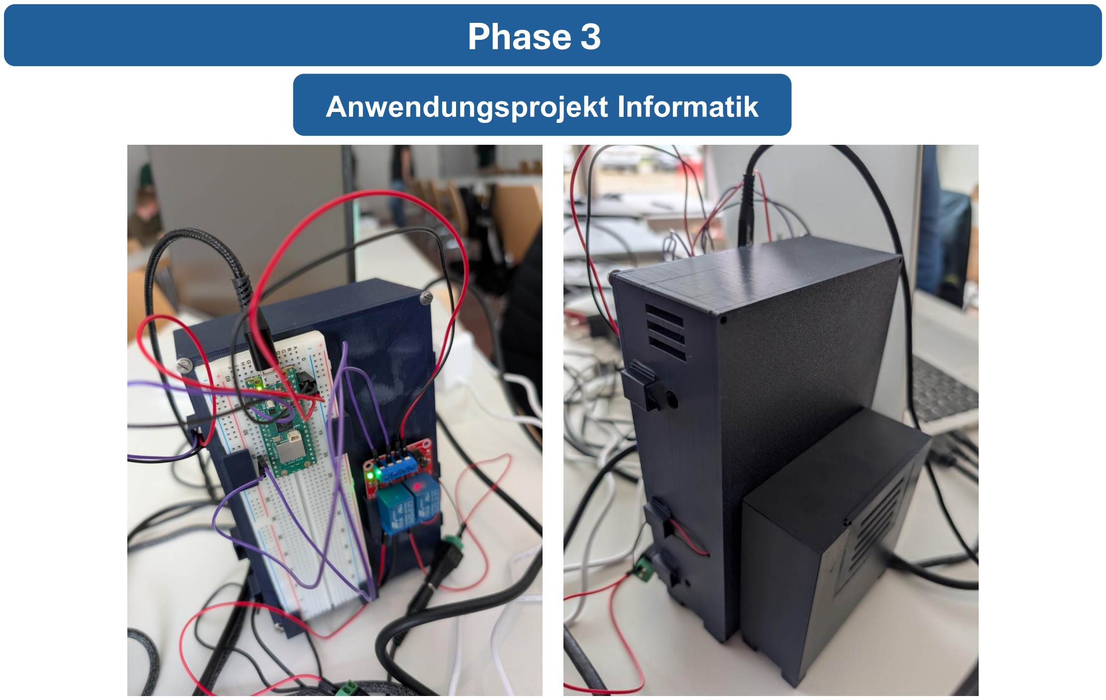
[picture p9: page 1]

# Struktur

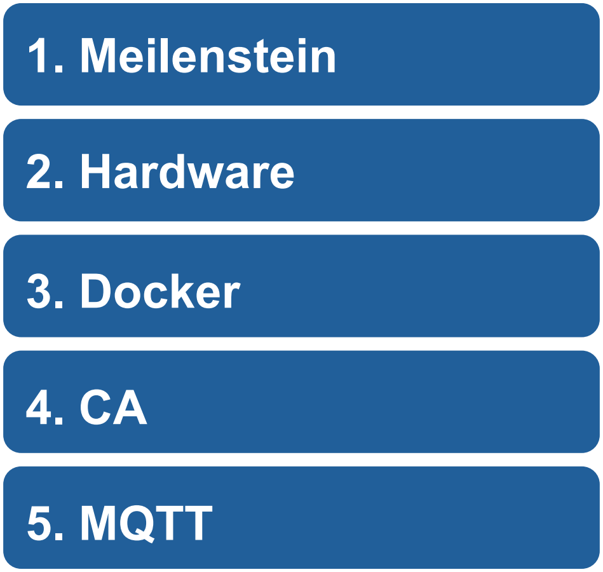
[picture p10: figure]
1. Meilenstein; 2. Hardware; 3. Docker; 5. MQTT

# 1. Meilenstein

## Sichere Übertragung der Sensordaten an MQTT

Sensordaten | Sicherer Kanal asynchron | Message-Broker

# 1. Meilenstein

## Benötigte Teilschritte

## Backend-Server

- Docker + Docker-Bridge
- Message-Broker als
Docker Container

## Certificate Authority (CA)

- CA auf Backend-Server
- Root-Zertifikat für CA
- Server-Zertifikat für
MQTT-Broker

# 1. Meilenstein

## Benötigte Teilschritte

## Mikro Python Programm

- Alle 60 Sekunden
DHT22 auslesen
- Topic ‘sensor/data‘
- Daten als JSON-String
- Authentifizierung

## Test der Integration

- MQTT-Client verwenden
- mosquitto_sub
- mosquitto_pub
- Korrektheit prüfen

# Aufgabenteilung

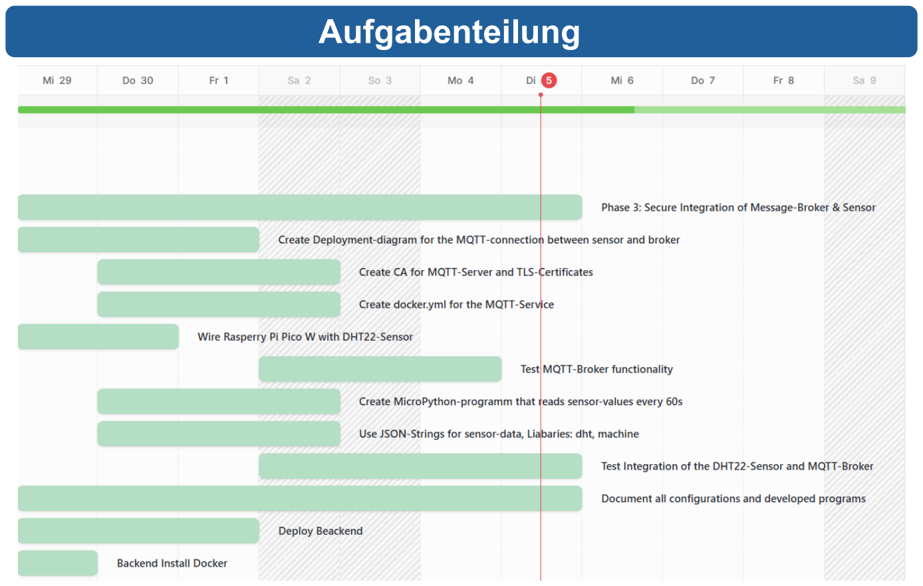
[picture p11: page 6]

# Deployment Diagramm

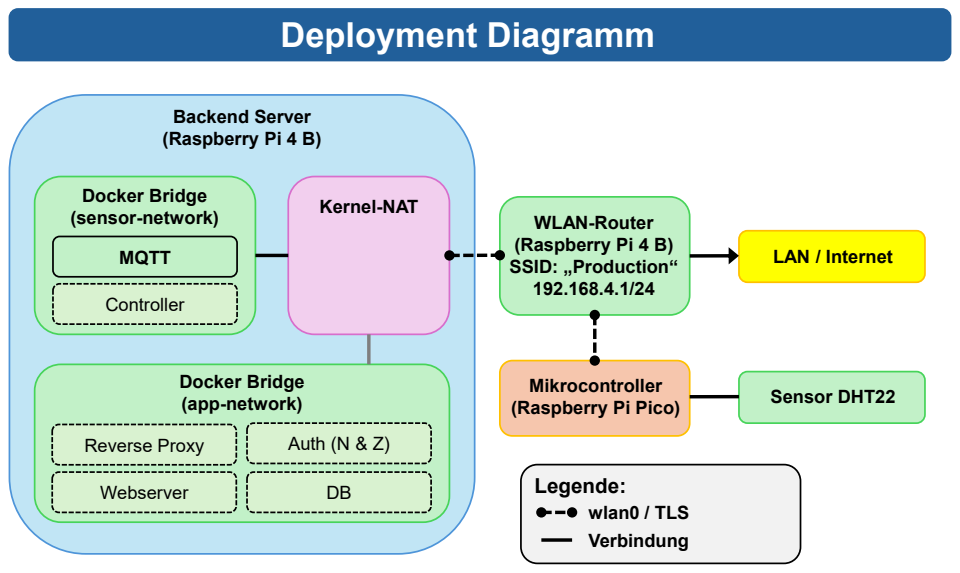
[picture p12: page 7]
Controller; MQTT; Docker Bridge (sensor-network); Webserver; Reverse Proxy; Auth (N & Z); Docker Bridge (app-network); Kernel-NAT; Backend Server (Raspberry Pi 4 B); WLAN-Router (Raspberry Pi 4 B) SSID: „Production“ 192.168.4.1/24; Mikrocontroller; (Raspberry Pi Pico); Sensor DHT22; LAN / Internet; wlan0 / TLS; Legende:; Verbindung

# 2. Hardware

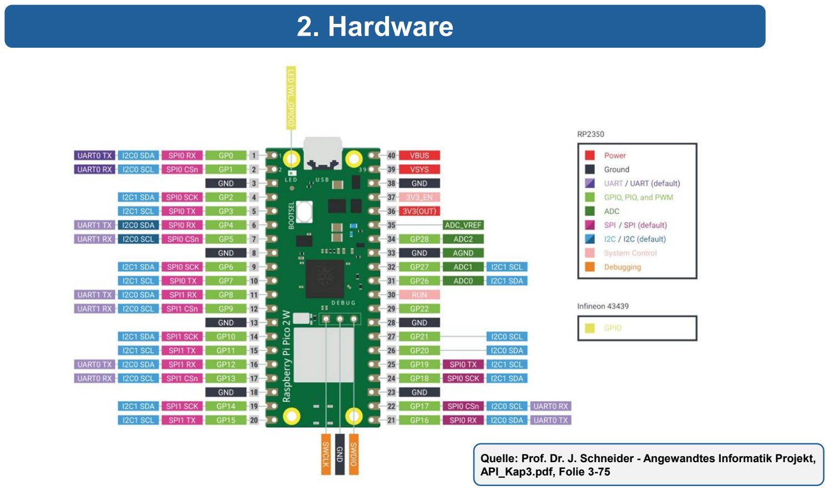
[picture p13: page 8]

Quelle: Prof. Dr. J. Schneider - Angewandtes Informatik Projekt, API_Kap3.pdf, Folie 3-75

# 2. Hardware – DHT-Sensor

## DHT22

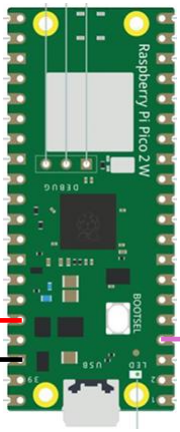
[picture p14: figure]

## Data GP2

## GND

## VCC +3.3V

# 2. Hardware

## Pico Ausschnitt main.py

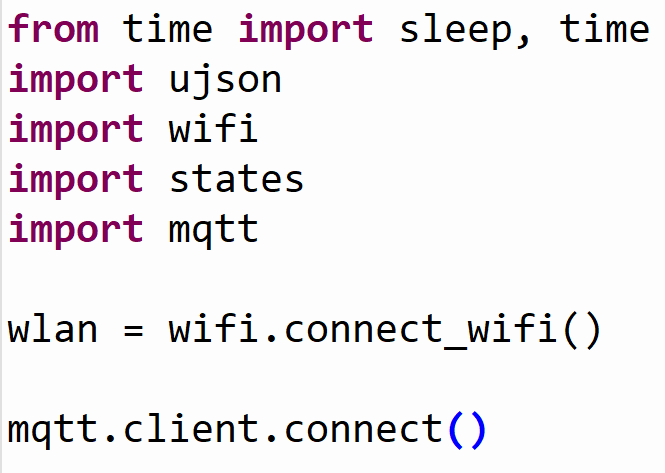
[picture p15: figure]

# 2. Hardware – Pico Mikro Python Loop

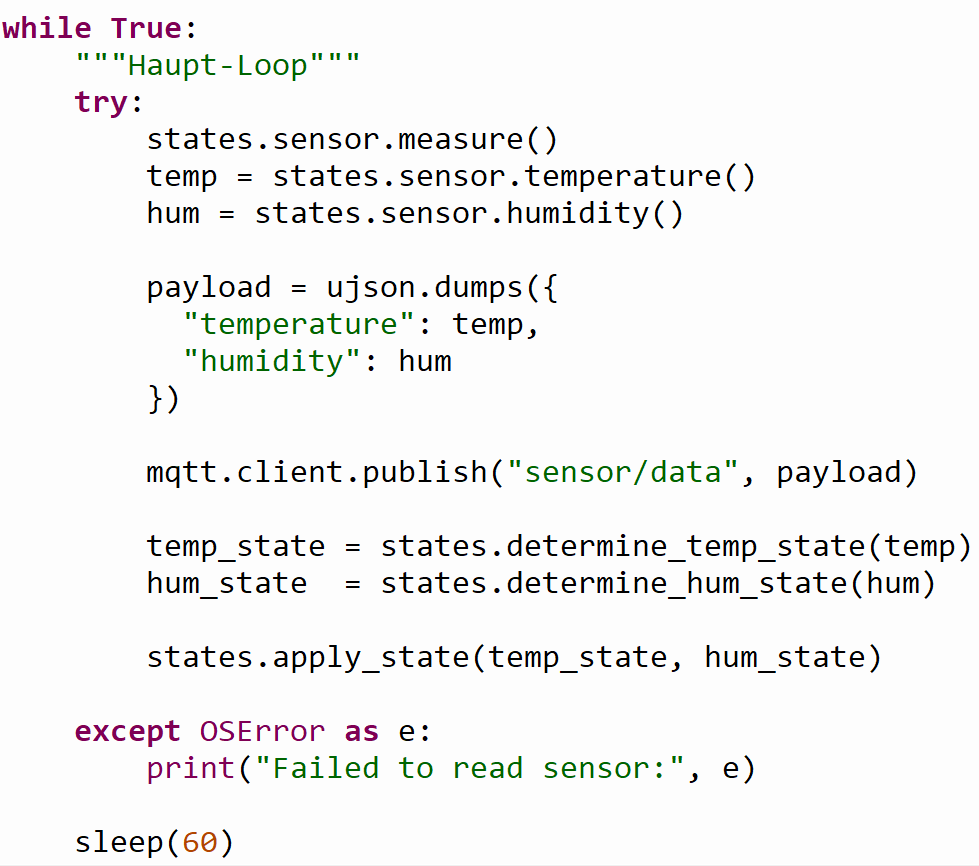
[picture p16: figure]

# 2. Hardware

## Pico Ausschnitt states.py

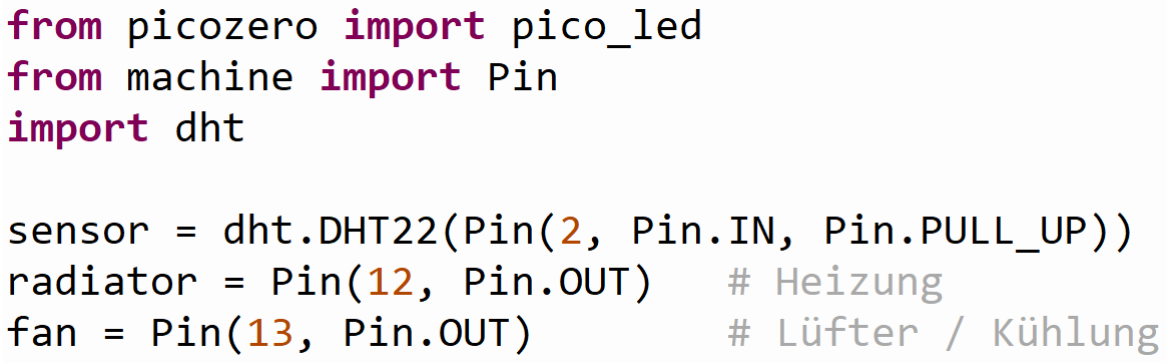
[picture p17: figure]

# 3. Docker – docker-compose.yml

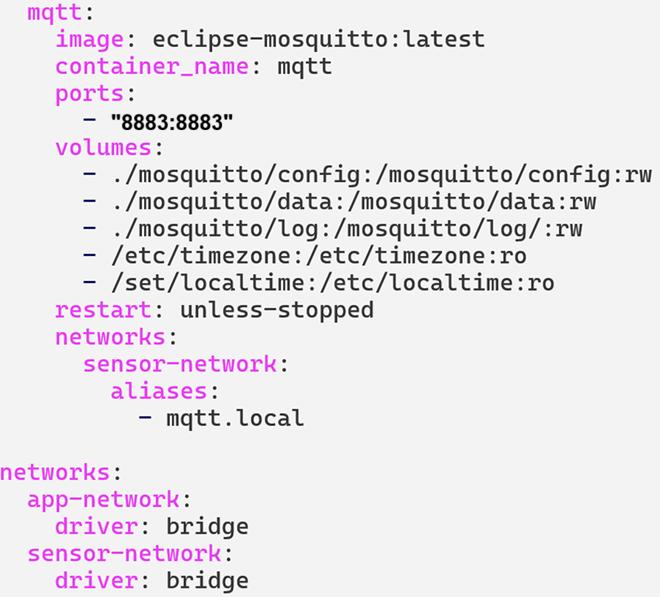
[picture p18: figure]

# 3. Docker

## Docker compose

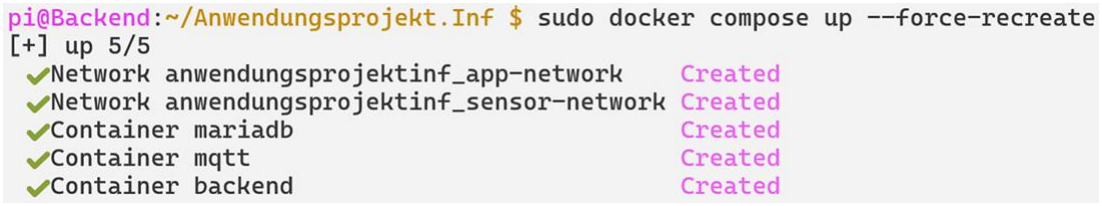
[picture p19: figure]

# 4. CA

## CA und mosquitto Struktur

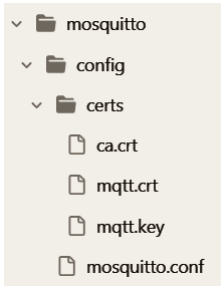
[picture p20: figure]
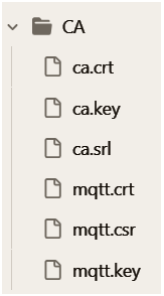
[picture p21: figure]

# 5. MQTT

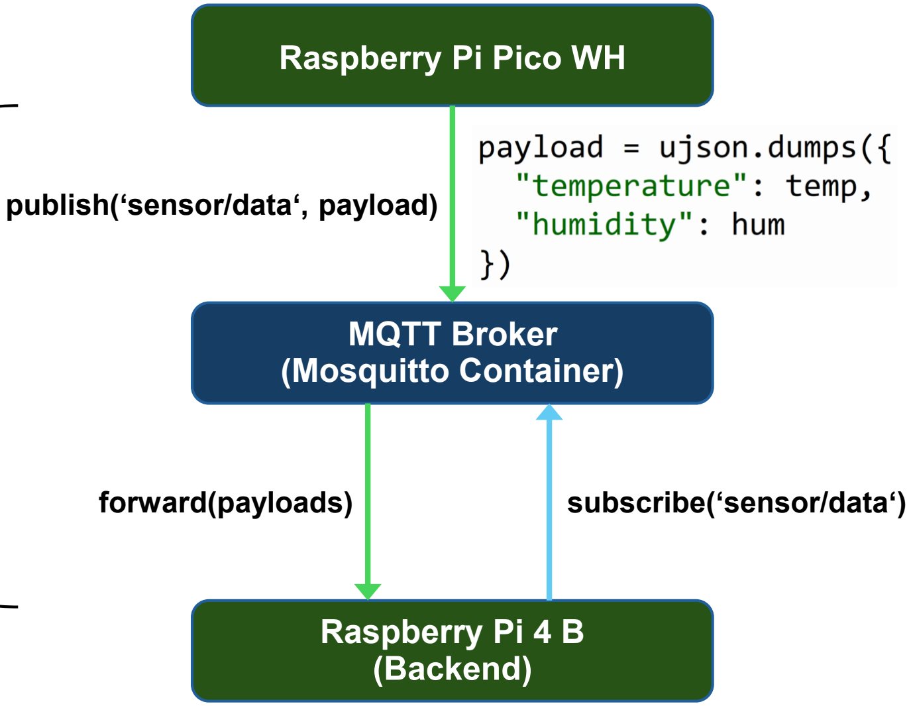
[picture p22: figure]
MQTT Broker (Mosquitto Container); Raspberry Pi Pico WH; Raspberry Pi 4 B (Backend); publish(‘sensor/data‘, payload); forward(payloads); subscribe(‘sensor/data‘)

Verschlüsselt

# 5. MQTT – mosquitto.conf

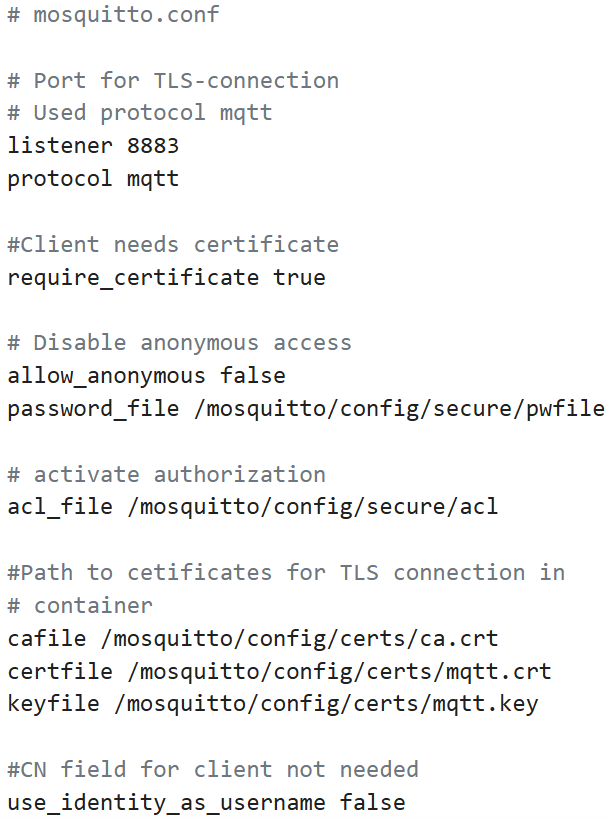
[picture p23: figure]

# 5. MQTT

## acl

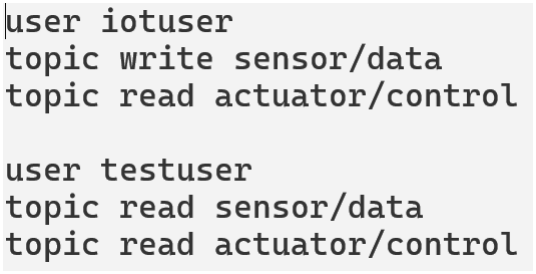
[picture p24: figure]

# 5. MQTT – Publish / Subscribe


# 5. MQTT

## Pico mqtt.py


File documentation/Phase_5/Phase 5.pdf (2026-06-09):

# Phase 5

Controlling an Actor via LSTM-NN-Tim Dorozynski

Barnabas Steiner - Benjamin Hager - Jannis Weber - Lennart Esch - Tim Dorozynski - Walter Neer

## Inhaltsverzeichnis

- Das Problem
- System Architektur
- Long Short-Term Memory
- LSTM-Training des Modells
- LSTM-Vorhersage
- Verdrahtung der Aktoren
- Fazit

## Das Problem

- Temperatur im Klebestand muss zwischen 19°C und 21°C bleiben.
- Reaktive Steuerung (z. B. "Heizung an, wenn <19°C")
ist zu langsam → Temperatur schwankt stark.
- Lösung: Vorhersage der Temperatur im Voraus
→ Aktoren schalten, bevor der Grenzwert erreicht wird

## System Architektur


## Long Short-Term Memory


- Wie verwenden
TensorFlow
- Dual-Stack LSTM
für Zeitreihenanalyse
- Eingabe: 10-Zeitschritte mit 2 Features
- Dropout (20%)
verhindert Overfitting
- Adam-Optimierer

## LSTM-Training des Modells


- Das Netz wurde mit
Sensordaten Trainiert
- Sie Sensordaten
werden aus einer CSV
geladen
- Damit werden die
weights für die KI
erstellt

## LSTM-Vorhersage


## Verdrahtung der Aktoren


- Raspberry Pi Pico WH
- Relais-Modul
- Eingänge: IN1, IN2 (Steuersignale)
- Stromversorgung: DC+, DC-
(3,3V vom Pico)
- Ausgänge: NO1/COM1/NC1 (Lüfter), NO2/COM2/NC2 (Heizung)
- Aktoren:
Lüfter: 12V
Heizung: 24V

## Fazit

- KI-Probleme: Vorhersage zu ungenau (±0,01°C)
→ Falsche Aktorsteuerung (z. B. 25°C → Vorhersage 20,96°C)
- Stromversorgung kritisch (500mA)
→ Instabilität durch LCD/Relais/Sensor
- MQTT-Verzögerungen (funktioniert, aber an der Grenze)
- IPs hatten sich geändert

## Vielen Dank für Eure Aufmerksamkeit!

Gibt es noch Fragen?

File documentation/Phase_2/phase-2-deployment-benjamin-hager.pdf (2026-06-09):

# Phase 2: Deployment

# Barnabas Steiner - Benjamin Hager - Jannis Weber - Lennart Esch Tim Dorozynski - Walter Neer

# Gliederung

# - Projektplan - Deployment-Diagramm - Bewertung der Architekur - AP-Konfiguration - Konfiguration der Firewall - Integration Microcontroller - Ergebnisstand - Verwendete Hilfsmittel

# Projektplan


# Deployment Diagramm


Sicherheitsprinzip- | Bewertung | Nötige Ergänzungen
Security-By-Design | ● Klare Trennung von Router, Backend und IoT-Netzwerk ● Kommunikationskanäle ersichtlich
Least Common Mechanism | ● Produktion hat eigenes Netzwerk ● Dockerbridges zur Kommunikationsminimierung | ● Darstellen von Nachrichtenqueues für Sensoren und Aktoren
Complete Mediation | ● Gatekeeping durch nftables und iptables | ● JWT-Token für Webnutzung hinzufügen
Least Privilege | ● Trenunng des Backends in app-net un sensor-net | ● Hinzufügen von Benutzerrollen
Fail-Secure Defaults | ● Absturz networkmanager -> sicherer Abbruch der Verbindung | ● Ip-Forwarding deaktiviert, wenn Firewall nicht startet
Defence in Depth | ● nftables am Router ● WPA2-Veschlüsselung ● iptables auf Backend-Pi ● Isolierung durch Docker

# AP-Konfiguration


# AP-Konfiguration - hotsapd, dnsmasq, IP-forwarding


# Konfiguration der Firewall - Filter-Tabelle


# Konfiguration der Firewall - NAT-Tabelle


# Integration Microcontroller - WLAN


# SSID: “Production” PASSWORD: “Production-01”

# - Anmeldung ins WLAN als Client - Verbindung in Schleife abwarten

# Integration Microcontroller - Temperaturabfrage


# - Abfrage Open-Meteo API - Extraktion der Temperatur aus JSON - Blinkrate durch Temperatur bestimmen:

# - temp < 10 ⇒ 2.0 - temp <= 25 ⇒ 1.0 - else ⇒ 0.3

# Ergebnisstand

# - Deploymentdiagramm für klare Übersicht der Architektur - Produktionsnetzwerk ist funktionfähig

# - Access-Point mit routing - Integration von Backend und IoT durch WLAN-Clients - Firewall reguliert Zugriffsberechtigungen

# Verwendete Hilfsmittel

# monday work management: Erstellung des Projektplanes und Aufgabenzuteilung

# draw.io: Erstellung des Deploymentdiagramms

# github: Austausch und Versionierung von Daten

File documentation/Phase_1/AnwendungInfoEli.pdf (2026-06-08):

Tabelle 1 — Initiales Requirement Management
| Kategorie | Beschreibung

Ausgangssituation /
Problemstellung

Der Klebeprozess in der Halbleiterproduktion leidet unter unkontrollierten Temperatur- und Luftfeuchtigkeitsschwankungen. Es gibt keine automatische Überwachung oder Steuerung. Im Störungsfall können Mitarbeiter nicht rechtzeitig eingreifen.

Projektziel

Entwicklung eines IoT-Prozesskontrollsystems, das Temperatur (19–21 °C) und Luftfeuchtigkeit (40–55 %) an der Klebestation (30×30×30 cm) automatisch überwacht, steuert und im Leitstand grafisch visualisiert. Das System muss sicher, kostengünstig (< 10.000 €) und innerhalb von 10
| Wochen betriebsbereit sein.

Stakeholder

Unternehmensleitung (Budget & Umsatz), Produktionsleiter (Auftraggeber, zuverlässige Produktion), Mitarbeiter im Leitstand (Anwender, Überwachung), IT-Mitarbeiter (Umsetzung & Betrieb)

Randbedingungen
(Budget, Zeit)

Budget: max. 10.000 € — Zeitrahmen: 10 Wochen — Hardware: günstige Mini-Computer (z. B. Raspberry Pi) — Software: Open Source — Kommunikation: WLAN — Firewall trennt WLAN vom Unternehmens-
| LAN

Offene Punkte

Genaue Sensortypen noch festzulegen — Archivierungskonzept (> 7 Tage / ≥ 3 Jahre) ausdetaillieren — Redundanzstrategie bei Sensorausfall — Zugriffsrollen im Dashboard definieren

Nächste Schritte

1. Machbarkeitsstudie erstellen und Produktionsleiter präsentieren (binnen 7 Tage) — 2. Vertieftes Requirement Engineering nach Freigabe — 3. Deployment-Diagramm erstellen — 4. PSP & Gantt-Diagramm für Phase 1
| erarbeiten

Tabelle 2 — Funktionale Anforderungen
Nr. | Funktion | Beschreibung | Prio (MoSCoW)

FA1 Sensormessung

| | Das System misst regelmäßig (z. B. alle 60 s) Temperatur und Luftfeuchtigkeit an der

Klebestation.

| | | Must

FA2 Datenübertragung

| | Messwerte werden vom Mikrocontroller sicher über WLAN/MQTT an den Backend-Server

übertragen.

| | | Must

FA3 Automatische

| Temperatursteuerung | Temperatur wird automatisch im Bereich 19–21 °C gehalten (Aktor: Heizung/Lüfter, Regelung

per LSTM).

| | | Must

FA4 Automatische

| Feuchtigkeitssteuerung | Luftfeuchtigkeit wird automatisch im Bereich 40
–55 % gehalten. | Must

FA5 Web-Dashboard

| (Visualisierung) | Mitarbeiter sehen den zeitlichen Verlauf von Temperatur und Luftfeuchtigkeit grafisch im

Leitstand.

| | | Must

FA6 Manueller Eingriff

| | Bei Ausfall der automatischen Steuerung können Mitarbeiter manuell über das Dashboard Aktoren

steuern.

| | | Must

Nr. | Funktion | Beschreibung | Prio (MoSCoW)

FA7 Datenspeicherung Kurzzeit Sensordaten werden für mindestens 7 Tage
online in einer Datenbank abrufbar gespeichert. Should

FA8 Datenspeicherung Langzeit

| | Ältere Daten werden für mindestens 3 Jahre archiviert und können bei Bedarf wieder eingespielt werden. | Should

Tabelle 3 — Nicht-funktionale Anforderungen
Nr. | Anforderung | Beschreibung | Prio (MoSCoW)

NFA1 Sicherheit –

| Verschlüsselung | Alle Sensor- und Steuerungsdaten werden verschlüsselt (TLS) übertragen, um Manipulation durch Unbefugte zu verhindern. | Must

NFA2 Authentifizierung &

| Autorisierung | Zugriff auf das Web-Dashboard nur mit gültigem
Benutzerkonto und Passwort (z. B. Keycloak/IAM). Must

NFA3 Netzwerkisolation

| | Das WLAN der Klebestation ist durch eine Firewall vom Unternehmens-LAN getrennt; eingehender Verkehr wird blockiert. | Must

NFA4 Verfügbarkeit /

| Zuverlässigkeit | Bei Ausfall der automatischen Steuerung muss manueller Eingriff weiterhin möglich sein (kein Single Point of Failure). | Must
NFA5 Kosteneffizienz | Gesamtkosten für Hardware und Software unter
| | 10.000 €; Software soll Open Source sein. | Must
NFA6 Wartbarkeit | Betrieb mit standardisierten Docker-Containern für
| | einfache Updates und Wartung. | Should

NFA7 Mobilität / WLAN

| | Kommunikation über WLAN, da die Klebestation häufig räumlich verschoben wird und Kabel nicht

praktikabel sind.

| | | Must

NFA8 Datenschutz (DSGVO)

| | Sensordaten sind keine personenbezogenen Daten — datenschutzrechtlich unkritisch, Compliance

dennoch prüfen.

| | | Should
NFA9 Benutzbarkeit | Das Dashboard muss für Leitstandmitarbeiter ohne
| | IT-Kenntnisse intuitiv bedienbar sein. | Could

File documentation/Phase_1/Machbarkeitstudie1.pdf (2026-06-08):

# Initiales Requirements Management

Kategorie | Beschreibung
Ausgangssituation / | | Temperatur- und Luftfeuchtigkeitsschwankungen beeinträchtigen die Verklebung an der Klebemaschine
Problemstellung
Projektziel | System zur automatischen Regulierung von Temperatur und Luftfeuchtigkeit einer Klebestation
Stakeholder | Produktionsleiter (Kunde), Entwicklung (wir)

Wichtige Funktionale
Anforderungen
| Lüfter und Heitzung-Ansteuerung; Messdateninterpretation; Temperaturregulation zwischen 19°C und 21°C Luftfeuchtigkeitsregulation zwischen 40% und 55%
| Zugriff über WLAN; Firewall; Grafische Ausgabe des Verlaufs von Temperatur und Luftfeuchtigkeit; Manipulationsschutz vor Unbefugten und Hackern; Sensorendaten für mindestens 7 Tage abrufbar; Datenarchivierung für mindestens 3 Jahre; Open Source Software Hardware aus günstigen Mini-Computern
| Budget: 10.000€ Deadline: 08.06.2026
Offene Punkte für Projekt | Softwarearchitektur; Softwareimplementierung; Installation; Systemprüfung

Wichtige nicht-funktionale Anforderungen

Randbedingungen (Budget,
Zeit)

festhalten

Nächste Schritte

Machbarkeitsstudie;

Requirement Engineering;

Projektstrukturplan erstellen;

# Machbarkeitsstudie

Technik | Gegenstand der Bewertung | Bewertung
Technische Machbarkeit | • Personal und Fachkompetenz • Hardware • Software | • Das Personal hat Vorkenntnisse in Web-Entwicklung und teilweise Elektrotechnik; es wird davon ausgegangen, dass andere benötigte Fachkenntnisse sich während der Entwicklung angeeignet werden • DIe Hardware wurde bereits zu Beginn des Projekts gestellt; es wird davon ausgegangen, dass diese aureicht, um alle angeforderten Funktionen zu erfüllen • Es kann ausschließlich Open-Source-Software verwendet werden, um die Anforderungen zu erfüllen
Wirtschaftliche Machbarkeit | • Investitionskosten • Entwicklungskosten • Wartungskosten • Betriebskosten | • Die eingesetzte Hardware ist bereits gestellt • Es wird konstenlose Software verwendet und die Entwickler werden nicht entlohnt -> es fallen keine Entwicklungskosten an • Da es keine Personalkosten gibt, entstehen keine Wartungskosten • Die Betriebskosten belaufen sich auf Stromverbrauch und möglichen Hardware-Verschleiß,
Organisatorische Machbarkeit | • Integration in bestehende Systeme • Fachkenntnisse für Betrieb | • keine bestehende Systemlandschaft -> keine Integration notwendig • Betrieb erfordert keine spezifischen Fachkenntnisse nach Demonstration
Zeitliche Machbarkeit | • Zeit für Kompetenzgewinn • Zeit für Entwicklungsarbeit | • Es ist davon auszugehen, dass alle benötigten Kompetenzen im Zeitrahmen des Projekts erworben werden können/müssen

| | • Ab dem 28.04.2026 ist die verfügbare Zeit für die Entwicklung ausreichend
Rechtliche Machbarkeit | • Personenbezogene Daten • Schutz erhobener Daten | • es werden keine personenbezogenen Daten erhoben • Daten können durch Security-By-Design geschützt werden
Risiken und Gegenmaßnahmen | • Frühere Abgabe • Verzug durch langsame Arbeit oder größeren Zeitaufwand in der Kompetenzaneignung | • Risiko: gering, Gegenmaßnahme: weinen • Risiko: wahrscheinlich, Gegenmaßnahme: Überstunden

# Machbarkeitsbericht

Das Projekt wird unter den oben angegebenen Umständen als durchführbar eingestuft.

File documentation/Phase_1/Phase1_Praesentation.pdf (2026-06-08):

ANWENDUNGSPROJEKT INFORMATIK | PHASE 1

# Projektmanagement für eine Automatisch Temp kontrolierte Klebestation

Planung – Zeitplan - Anforderungen - Machbarkeit - Deployment

Jannis Weber


Alle 6 Phasen:

Phase 1:


Gant Diagramm:

Kategorie | Beschreibung
Ausgangssituation / Problemstellung | Temperatur- und Luftfeuchtigkeitsschwankungen beeinträchtigen die Verklebung an der Klebemaschine
Projektziel | System zur automatischen Regulierung von Temperatur und Luftfeuchtigkeit einer Klebestation
Stakeholder | Produktionsleiter (Kunde), Entwicklung (wir)
Wichtige Funktionale Anforderungen | Lüfter und Heitzung-Ansteuerung; Messdateninterpretation; Temperaturregulation zwischen 19°C und 21°C Luftfeuchtigkeitsregulation zwischen 40% und 55%

Wichtige nichtfunktionale
Anforderungen

Zugriff über WLAN;
Firewall;
Grafische Ausgabe des Verlaufs von Temperatur und Luftfeuchtigkeit; Manipulationsschutz vor Unbefugten und Hackern;
Sensorendaten für mindestens 7 Tage

Sensorendaten für mindestens 7 Tage abrufbar;
Datenarchivierung für mindestens 3 Jahre;
Open Source Software
Hardware aus günstigen Mini-Computern
Randbedingungen
(Budget, Zeit)

Budget: 10.000€
Deadline: 08.06.2026
Offene Punkte für
Projekt festhalten

Softwarearchitektur;
Softwareimplementierung; Installation; Systemprüfung
Nächste Schritte | Machbarkeitsstudie;
| Requirement Engineering;
| Projektstrukturplan erstellen;


Technik | Gegenstand der Bewertung | Bewertung
| | Web/Elektrotechnik • Rest wird angeeignet
| Hardware | • Bereits gestellt • Ausreichend für Anforderungen
| Software | • Nur Open-Source
| | • Open-Source -> keine Lizenzkosten
| Wartungs- / Betriebskosten | • Keine Personalkosten • Nur Strom + ggf. Verschleiß
Technische Machbarkeit | Personal & Fachkompetenz | • Vorkenntnisse
Wirtschaftliche Machbarkeit | Investitions- / Entwicklungskosten | • Hardware bereits gestellt
Organisatorische Machbarkeit | Integration & Betrieb | • Keine bestehende Systemlandschaft • Einweisung per Demonstration

Machbarkeitsstudie

Zeitliche Machbarkeit | Kompetenzgewinn & Entwicklungszeit | • Aufbau im Projektzeitraum machbar • Ab 28.04.2026 Zeit ausreichend
Rechtliche Machbarkeit | Daten & Datenschutz | • Keine personenbezogenen Daten • Schutz durch Security-By-Design
Risiken & Gegenmaßnahmen | Frühe Abgabe (gering) | • Zeitpuffer einplanen
| Verzug Kompetenzaufbau (wahrsch.) | • Mehrarbeit / Überstunden

Machbarkeitsbericht:

Das Projekt wird unter den oben angegebenen Umständen als durchführbar eingestuft.


Deployment-Diagramm

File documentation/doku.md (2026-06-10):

# Temperatur- und Luftfeuchtigkeitsregulierer

In diesem Projekt wurde ein Regulierungssystem für Luftfeuchtigkeit und Temperatur entwickelt, dass die Messdaten sicher
speichert und für einen authentifizierten Nutzer die Messdaten der letzten Woche visualisiert.  
Zielwerte für die Temperatur sind zwischen 19 °C und 21 °C und für die Luftfeuchtigkeit zwischen 40 % und 55 %.
Das Projekt wurde bewältigt durch:
* Tim Dorozynski
* Lennart Esch
* Benjamin Hager
* Walter Neer
* Barnabas Steiner
* Jannis Weber

## Anforderungen und Struktur

Die Anforderungen für das Endprodukt waren die folgenden:

**Funktionale Anforderungen:**

| Nr. | Funktion | Beschreibung | Prio |
|-----|---|---|---|
| FA1 | Sensormessung | Das System misst regelmäßig (z. B. alle 60 s) Temperatur und Luftfeuchtigkeit an der Klebestation. | Must |
| FA2 | Datenübertragung | Messwerte werden vom Mikrocontroller sicher über WLAN/MQTT an den Backend-Server übertragen. | Must |
| FA3 | Automatische Temperatursteuerung | Temperatur wird automatisch im Bereich 19–21 °C gehalten (Aktor: Heizung/Lüfter, Regelung per LSTM). | Must |
| FA4 | Automatische Feuchtigkeitssteuerung | Luftfeuchtigkeit wird automatisch im Bereich 40–55 % gehalten. | Must |
| FA5 | Web-Dashboard (Visualisierung) | Mitarbeiter sehen den zeitlichen Verlauf von Temperatur und Luftfeuchtigkeit grafisch im Leitstand. | Must |
| FA6 | Manueller Eingriff | Bei Ausfall der automatischen Steuerung können Mitarbeiter manuell über das Dashboard Aktoren steuern. | Must |
| FA7 | Datenspeicherung Kurzzeit | Sensordaten werden für mindestens 7 Tage online in einer Datenbank abrufbar gespeichert. | Should |
| FA8 | Datenspeicherung Langzeit | Ältere Daten werden für mindestens 3 Jahre archiviert und können bei Bedarf wieder eingespielt werden. | Should |

**Nicht-funktionale Anforderungen:**

| Nr.  | Anforderung | Beschreibung | Prio |
|---|---|---|---|
| NFA1 | Sicherheit – Verschlüsselung | Alle Sensor- und Steuerungsdaten werden verschlüsselt (TLS) übertragen. | Must |
| NFA2 | Authentifizierung & Autorisierung | Zugriff auf das Web-Dashboard nur mit gültigem Benutzerkonto und Passwort (z. B. Keycloak/IAM). | Must |
| NFA3 | Netzwerkisolation | Das WLAN der Klebestation ist durch eine Firewall vom Unternehmens-LAN getrennt; eingehender Verkehr wird blockiert. | Must |
| NFA4 | Verfügbarkeit / Zuverlässigkeit | Bei Ausfall der automatischen Steuerung muss manueller Eingriff weiterhin möglich sein (kein Single Point of Failure). | Must |
| NFA5 | Kosteneffizienz | Gesamtkosten für Hardware und Software unter 10.000 €; Software soll Open Source sein. | Must |
| NFA6 | Wartbarkeit | Betrieb mit standardisierten Docker-Containern für einfache Updates und Wartung. | Should |
| NFA7 | Mobilität / WLAN | Kommunikation über WLAN, da die Klebestation häufig räumlich verschoben wird und Kabel nicht praktikabel sind. | Must |
| NFA8 | Datenschutz (DSGVO) | Sensordaten sind keine personenbezogenen Daten — datenschutzrechtlich unkritisch, Compliance dennoch prüfen. | Should |
| NFA9 | Benutzbarkeit | Das Dashboard muss für Leitstandmitarbeiter ohne IT-Kenntnisse intuitiv bedienbar sein. | Could  |

Zur Erarbeitung des
Projekts wurde dieses in die folgenden 6 Phasen eingeteilt:

1. Planung und Einteilung der folgenden Phasen
2. Erstellen eines WLAN Access Points mit Firewall
3. Verdrahtung des Pico und Übertragen der Sensordaten an das Backend
4. Sicheres Speichern der Sensordaten in der Datenbank
5. Steuerung der Aktoren des Pico mittels LSTM-Netz
6. Erstellen einer sicheren Webapplikation für die Sensordaten

## Phasen (patchnotes)

Die Präsentationen zu den einzelnen Phasen sind als PDF im jeweiligen Verzeichnis zu
finden.  
Im Folgenden sind die konkreten Änderungen während der einzelnen Phasen aufgegliedert:

### Phase 1:

Datum: 11.04.2026 - 23.04.2026  
Problemstellung: Planung des Projektes und dessen 6 Phasen  
Verantwortlicher: Jannis Weber  
Projektplan: Gantt_Phase1.pdf

| Datei | Änderung | Erklärung |
|---|---|---|
| [AnwendungInfoEli.pdf](Phase_1/AnwendungInfoEli.pdf) | N/A | Beschreibung der Anwendung und Projektidee mit Zielsetzung und Rahmenbedingungen |
| [Machbarkeitstudie1.pdf](Phase_1/Machbarkeitstudie1.pdf) | N/A | Machbarkeitsstudie zur technischen und wirtschaftlichen Umsetzbarkeit des Projektes |
| [6Phasen.png](Phase_1/6Phasen.png) | N/A | Erstmalige Verteilung der ersten Phasen |

**Machbarkeitsstudie:**

| Technik | Gegenstand der Bewertung | Bewertung |
|---|---|---|
| Technische Machbarkeit | Personal und Fachkompetenz; Hardware; Software | Vorkenntnisse in Web-Entwicklung und teilweise Elektrotechnik vorhanden; Hardware bereits gestellt; ausschließlich Open-Source-Software verwendbar |
| Wirtschaftliche Machbarkeit  | Investitionskosten; Entwicklungskosten; Wartungskosten; Betriebskosten | Hardware bereits gestellt; kostenlose Software, keine Personalkosten; Betriebskosten beschränken sich auf Stromverbrauch und möglichen Hardware-Verschleiß |
| Organisatorische Machbarkeit | Integration in bestehende Systeme; Fachkenntnisse für Betrieb | Keine bestehende Systemlandschaft, keine Integration notwendig; Betrieb erfordert keine spezifischen Fachkenntnisse nach Demonstration |
| Zeitliche Machbarkeit | Zeit für Kompetenzgewinn; Zeit für Entwicklungsarbeit | Benötigte Kompetenzen können im Zeitrahmen erworben werden; ab dem 28.04.2026 ist die verfügbare Entwicklungszeit ausreichend |
| Rechtliche Machbarkeit | Personenbezogene Daten; Schutz erhobener Daten | Keine personenbezogenen Daten erhoben; Daten können durch Security-By-Design geschützt werden |
| Risiken und Gegenmaßnahmen | Frühere Abgabe; Verzug durch langsame Arbeit oder größeren Zeitaufwand bei Kompetenzaneignung | Risiko gering; Verzug wahrscheinlich, Gegenmaßnahme: Überstunden |

**Machbarkeitsbericht:** Das Projekt wird unter den oben angegebenen Umständen als durchführbar eingestuft.

Plan für die nächsten Phasen:  
Phasenplan

### Phase 2:

Datum: 11.04.2026 - 28.04.2026  
Problemstellung: Deployment der Kern-Infrastruktur  
Verantwortlicher: Benjamin Hager  
GANT-Diagramm:
GANT Diagramm Phase 2
Deployment-Diagramm:
Deployment Diagramm Phase 2

| Datei | Änderung | Erklärung |
|---|---|---|
| configurations/wlan_ap_setup.py | Neu erstellt, danach mehrfach überarbeitet (Firewall-Regeln korrigiert, SSH auf allen Interfaces erlaubt, Quellen ergänzt) | Python-Skript zur Einrichtung eines WLAN-Access-Points auf dem Raspberry Pi: konfiguriert hostapd, dnsmasq, statische IP (192.168.4.1), IP-Forwarding und nftables-Firewall mit NAT (Masquerading über eth0). Ermöglicht das Produktionsnetzwerk "Production" für IoT-Clients. |
| configurations/pico_main.py | Neu erstellt, danach erweitert (Phase 2 Integration) | MicroPython-Skript für den Raspberry Pi Pico W: verbindet sich als WLAN-Client mit dem Produktionsnetzwerk, ruft die Außentemperatur aus Friedrichshafen via Open-Meteo-API ab und steuert die Onboard-LED (Blinkrate abhängig von Temperatur: <10°C → 2s, ≤25°C → 1s, >25°C → 0.3s). |
| pico_wlan_connection.txt | Neu erstellt, danach angepasst | Dokumentation/Notizen zur WLAN-Konfiguration des Pico W (SSID, Passwort, Verbindungsaufbau). |

### Phase 3:

Datum: 29.04.2026 - 05.05.2026  
Problemstellung: Sichere Übertragung der Sensordaten an MQTT  
Verantwortlicher: Walter neer  
GANT-Diagramm:
GANT Diagramm Phase 3  
Deployment-Diagramm:  
Deployment Diagramm Phase 3

| Datei | Änderung | Erklärung |
|---|---|---|
| configurations/pico_main.py | In Module aufgeteilt | Aufgrund von Erweiterungen des Codes, für die Übersichtlichkeit in Module mit eigener Zuständigkeit aufgeteilt |
| configurations/pico/iot_config.py | Neu | Enthält alle Variablen für die Konfiguration von MQTT, CA und WLAN |
| configurations/pico/control.py | Neu | Initialisierung der Pico Pins und Zuweisung an Sensor und Aktoren |
| configurations/pico/wifi.py | Neu | Zuständig für Konfiguration und Aufbau einer WLAN-Verbindung |
| configurations/pico/mqtt.py | Neu | Zuständig für Konfiguration, Verarbeitung und Aufbau einer MQTT-Verbindung mit CA |
| configurations/pico/states.py | Neu | Steuert Aktoren je nach erhaltener Anweisung mit Zustandsinformation |
| configurations/pico/main.py | Neu | Hauptdatei des Pico, wird als erstes ausgeführt und ist für den Programmablauf verantwortlich |
| configurations/pico/lib/picozero | Schon in Phase 2 enthalten | Bibliothek für die Ansteuerung der On-Board-LED des Pico |
| configurations/pico/lib/umqtt | Neu | Bibliothek für MQTT relevante Funktionen, enthält simple.py und robust.py |
| configurations/pico/lib/lcd_api.py | Neu | Basisklasse für den Aufbau einer I2C-Verbindung |
| configurations/pico/lib/pico_i2c_lcd.py | Neu | Enthält Methoden für das Ansteuern eines LCD-Displays über den Pico, verwendet die Basisklasse aus lcd_api.py |
| CA/ca.key | Neu | Private Schlüsseldatei der CA, zum signieren von Zertifikaten |
| CA/ca.srl | Neu | Seriennummerndatei der CA, enthält Seriennummern von signierten Zertifikaten |
| CA/ca.crt | Neu | Öffentliches Zertifikat der CA, zum prüfen der Signatur anderer Zertifikate |
| CA/ca.der | Neu | Wie ca.crt aber als Binärdatei statt Text, damit der Pico damit arbeiten kann |
| CA/req.cnf | Neu | Konfigurationsdatei für OpenSSL mit Einstellungen für beispielsweise Erweiterungen (weitere Hostnamen), wird für mqtt.csr und ca.crt verwendet |
| CA/mqtt.key | Neu | Privater Schlüssel des MQTT-Servers, wird für TLS-Verschlüsselung benutzt |
| CA/mqtt.csr | Neu | Wird aus mqtt.key erzeugt, für das Erhalten eines Zertifikats vom CA |
| CA/mqtt.crt | Neu | Signiertes Zertifikat des MQTT-Brokers, vom ca.key signiert, Beweis für Clients, dass das Zertifikat über CA gültig ist |
| docker-compose.yml | Neu, Konfiguration für mqtt-Container hinzugefügt | Konfiguration mit eclipse-mosquitto Image und Port 8883, benötigte volumes gemountet |
| mosquitto/config/mosquitto.conf | Neu | Konfigurationsdatei für den MQTT-Broker |
| mosquitto/log/mosquitto.log | Neu | Logdatei für den MQTT-Broker |
| mosquitto/secure/acl | Neu | Angelegte Nutzer und deren Zugriffsrechte auf topics |
| mosquitto/secure/pwfile | Neu | Existierende Nutzer und deren verschlüsselte Zugangsdaten |

### Phase 4:

Datum: 06.05.2026 - 12.05.2026  
Problemstellung: Sichere Übermittlung der Sensordaten und Speicherung in der Datenbank  
Verantwortlicher: Lennart Esch  
GANT-Diagramm:
GANT Diagramm Phase 4  
Deployment-Diagramm:  
Deployment-Diagramm Phase 4

| Datei | Änderung | Erklärung |
|---|---|---|
| controller/config.py | Neu | Liest Environment Variablen aus der Dockerfile |
| controller/controller.py | Neu | Main Datei des controllers |
| controller/Dockerfile | Neu | Dockerfile, um aus dem Controller ein Image zu bauen, enthält die definierten Environment Variablen |
| controller/https_client.py | Neu | Verwendet die Request Library um https requests zu schicken; wird verwendet für das Weiterleiten der Daten an nginx |
| controller/mqtt_handler.py | Neu | Verwendet die paho_mqtt Library um beim mqtt-Broker zu subscriben, definiert ein Event, das ausgelöst wird wenn eine Nachricht vom Broker eingeht |
| controller/validation.py | Neu | Kontrolliert, ob die vom Broker erhaltene Nachricht valides JSON ist und prüft, ob die Werte plausibel sind (wird relevant, wenn der Pico angesteurt werden soll) |
| nginx/nginx.conf | Neu | Konfiguration von nginx, reverse Proxy von https local.data.kleber zum webapp server und redirect von http auf https |
| webapp/Dockerfile | Neu | Dockerfile zum Bau eines Images für den webserver |
| webapp/package.json | Neu | Node Standard-Konfigurationsdatei für den webserver |
| webapp/package-lock.json | Neu | Node Standard-Konfigurationsdatei für den webserver |
| webapp/server.js | Neu | Controller + Service-Layer für den webserver, enthält POST-Endpunkt zum Empfangen von neuen Messdaten und anlegen neuer Messwerte in der Datenbank |
| webapp/config/database.js  | Neu | Erzeugt einen Connection-Pool für den Datenbank Zugriff, der von ´server.js´ verwendet wird |
| mariadb/01_tables.sql | Neu | Initialscript für die Datenbank; legt die Tabellen für Messwerte und Messwertarchiv an |
| mariadb/02_archive_job.sql | Neu | Initialscript für die Datenbank; legt den Archivierungsjob an; es werden täglich alle Daten, die älter als eine Woche sind von `sensor-data` zum `sensor-data-archive` verschoben |
| mariadb/03_user.sql | Neu | Initialscript für die Datenbank; legt einen Nutzer mit Schreibrechten für `sensor-data` an |
| docker-compose.yml | Konfiguration für die neuen Services hinzugefügt | Datenbank Konfiguration mit Health-Check und Verweiß auf die Entry Point Skripte hinzugefügt<br/>Nginx Configuration basierend auf dem OWASP/modsecurity-crs Image hinzugefügt, enthält bereits Schutzmaßnahmen gegen Cross-Site-Scripting, SQL-Injektion und Directory Traversal<br/>Webapp Konfiguration basierend auf dem Image aus der Dockerfile hinzugefügt<br/>Controller Konfiguration basierend auf dem Image aus der Dockerfile hinzugefügt |

### Phase 5:

Datum: 13.05.2026 - 21.05.2026  
Problemstellung: Steuerung eines Aktors mittels LSTM-Neuronales Netz  
Verantwortlicher: Tim Dorozynski  
GANT-Diagramm:
GANT Diagramm Phase 5  
Deployment-Diagramm:  
Deployment-Diagramm Phase 5

| Datei | Änderung | Erklärung |
|---|---|---|
| controller/lstm_handler.py | Neu | Lädt das trainierte LSTM-Modell und stellt Funktionen zur Verfügung, um Vorhersagen zu treffen; wird verwendet, um den optimalen Aktor-Wert basierend auf Sensor-Eingaben zu berechnen |
| controller/train.keras | Neu | Trainiertes Keras/TensorFlow LSTM-Modell; Gewichte und Architektur für die Vorhersage des optimalen Regelwertes |
| controller/train.py | Neu | Trainingsscript für das LSTM-Modell; verwendet historische Messdaten um das Netz zu trainieren |
| controller/model_trainer.py | Neu | Modulare Trainingsfunktionen für das LSTM-Modell; ermöglicht automatisches Retraining basierend auf neuen Daten |
| controller/data_generation.py | Neu | Generiert Trainingsdaten aus Temperatur, Luftfeuchtigkeit, Heizung und Cooler; Daten werden algorithmisch generiert, um dem LSTM Ursache/Wirkung der Aktoren beizubringen |
| controller/lstm_weights.weights.h5 | Neu | Exportierte Gewichte des trainierten LSTM-Modells; ermöglicht schnelleres Laden des Modells ohne Retraining |
| configurations/pico/control.py | Neu | Stellt Funktionen zur Ansteuerung des physischen Aktors (z.B. Heizung/Lüfter) bereit; implementiert PWM-Steuerung oder digitale Schaltausgänge |
| configurations/pico/states.py | Neu | Verwaltet die Zustände des Systems und des Aktors; definiert die möglichen Aktor-Positionen und deren Bedeutung |
| docker-compose.yml | LSTM-Umgebungsvariablen im Controller-Service hinzugefügt | Ermöglicht Konfiguration des LSTM-Modells und Trainingparameter über Umgebungsvariablen; aktiviert LSTM-Vorhersagen im Controller |
| controller/Dockerfile | TensorFlow/Keras Dependencies hinzugefügt | Integriert erforderliche Python-Libraries (tensorflow, keras, numpy, scikit-learn) für LSTM-Modellverarbeitung im Container |

### Phase 6:

Datum:  22.05.2026 - 28.05.2026    
Problemstellung:  Sichere Web-Applikation (AuthN/AuthZ mit Keycloak)    
Verantwortlicher:  Barnabas Steiner    
GANT-Diagramm:    
GANT Diagramm Phase 6  
Deployment-Diagramm:  
Deployment Diagramm Phase 6

| Datei | Änderung | Erklärung |
|---|---|---|
| docker-compose.yml | Service `keycloak_web` + Volume `keycloak_data` ergänzt, DB-Credentials in read/write getrennt, Healthchecks & `depends_on` | Integriert Keycloak als OIDC-Provider, hält dessen Daten persistent und sorgt für geordneten Startup der abhängigen Services |
| keycloak/iot-realm.json | Realm `iot` mit Rollen (`dashboard-user`, `admin-user`, `controller-ingest`), Benutzern und Clients angelegt | Definiert die Sicherheitsdomäne: `dashboard-client` (Browser, PKCE) und `controller-client` (Maschine, Client-Credentials) |
| nginx/nginx.conf | Route `/auth` auf Keycloak (Port 8443) + TLS-Zertifikatsprüfung, Trailing-Slash-Fix | Macht Keycloak über den Reverse Proxy erreichbar und verschleiert das interne System |
| mariadb/03_db_write_user.sql | Aus `03_user.sql` umbenannt; Schreib-User `websrv_write` (INSERT, UPDATE) | Trennt schreibende DB-Zugriffe vom Lesen (Least Privilege) |
| mariadb/06_db_read_user.sql | Neuer Lese-User `websrv_read` mit `SELECT` auf `sensor_data` | Lese-APIs erhalten ausschließlich Leserechte |
| mariadb/05_training_data_privileges.sql | Privilegien an die Read/Write-Trennung angepasst | Konsistente Rechtevergabe nach der User-Aufteilung |
| webapp/config/database.js | `getReadPool()` / `getWritePool()` statt einem `getPool()` | Jeder Pool meldet sich mit eigenem DB-User an → Least Privilege auf Verbindungsebene |
| webapp/server.js | JWKS-Client + Middleware `authenticateToken`; neuer Endpoint `GET /api/sensordata` | Prüft das JWT (Signatur, Audience, Rolle `dashboard-user`); liefert Dashboard-Daten per JWT statt API-Key |
| webapp/package.json / package-lock.json | Dependencies `jwks-rsa` und `jsonwebtoken` ergänzt | Bibliotheken zur serverseitigen Token-Validierung |
| webapp/public/index.html | Keycloak-Login-Redirect + Einbindung lokaler `keycloak.js` | Leitet nicht angemeldete Nutzer zur Keycloak-Loginseite weiter |
| webapp/public/keycloak.js | Neue lokale Kopie der Keycloak-JS-Bibliothek | Auslieferung über die eigene App statt über eine externe Quelle |
| webapp/public/frontend.js | Keycloak-Init + Sensordaten-Abruf per `fetch()` mit `Bearer`-Token | Initiiert AuthN/AuthZ und lädt Daten vom geschützten Endpoint |
| webapp/public/chart.js | Diagramm-Rendering + Live-Update implementiert | Visualisiert Temperatur/Luftfeuchte, minütliche Aktualisierung |
| webapp/public/style.css | Styling-/Layout-Anpassungen | Optische Gestaltung des Dashboards |
| webapp/Dockerfile | Aus Root-`Dockerfile` nach `webapp/` verschoben | Trennt den Web-App-Build vom Projekt-Root |
| sensor-net/keycloak_auth.py | Neu: Client-Credentials-Flow, Token-Cache, Rollenprüfung, Bearer-Header | Controller authentifiziert sich maschinell an Keycloak statt nur per API-Key |
| sensor-net/http_client.py | `_build_headers()` (API-Key + Bearer); `verify=False` → `verify=CA_CERT_PATH` | Zentrale Header-Erzeugung inkl. Token; echte TLS-Zertifikatsprüfung |
| sensor-net/controller.py | `verify_role()` vor `warmstart()`; TLS-Verify aktiviert | Beendet den Controller, wenn die geforderte Keycloak-Rolle fehlt |
| sensor-net/config.py | `KC_*`-Variablen (Token-URL, Client-ID/-Secret, Rolle) + `CA_CERT_PATH` ergänzt | Konfigurierbare Keycloak-Parameter für den Controller |
| sensor-net/Dockerfile | ENV-Defaults für die Keycloak-Variablen | Standardwerte für den Containerbetrieb |
| sensor-net/mqtt_handler.py | Sendet Temperatur statt Prognose an `training_data` | Korrigiert den an die Trainingsdaten übermittelten Wert |
| configurations/wlan_ap_setup.py | Backend unter eigenem Hostnamen im Produktions-WLAN | Namensauflösung für den Zugriff auf das Backend |

### Endspurt:

Liste mit übrigen Aufgaben

| Datei | Änderung | Erklärung |
|---|---|---|
| CA/* | Neugennerierung aller Zertifikate; Alle Zertifikate sind jetzt unter CA abgelegt | Aufgrund von Schwierigkeiten bei den Zertifikaten wurden alle Zertifikate neu erstellt und befinden sich nun im CA Verzeichnis |
| environment/* | Environment Variablen wurden von der docker-compose und den Dockerfiles in dieses Verzeichnis nach dem Namensschema [container_name].env ausgelagert | Die Environment Dateien sind jetzt an einem Ort gebündelt; <br/>Es war geplant die Applikation so zu gestalten, dass die Änderungen in den environment Dateien reichen, um alle notwendigen Änderungen auf das gesammte Projekt auszuweiten;<br/> Aus Zeitdruck wurde das leider nicht mehr erreicht |
| docker-compose.yml | Anpassung an obere Änderungen; docker-compose stellt den Services die Zertifikate jetzt über volumes zur Verfügung | Die Zertifikate lagen vorher als Kopie im jeweiligen Verzeichnis, in dem sie gebraucht wurden; <br/>Jetzt werden die Zertifikate nur unter CA abgelegt und von der docker-compose als volumes in die Container gemounted |
| controller/train.py | Entfernt | Wurde nicht mehr benötigt, weil die Trainingsmethode von model_trainer.py effizienter ist. |
| mariadb/05_db_admin_user.sql | Neu | Für Least Priviliges wird ein neuer User benötigt, um die erweiterten Rechte des Admins abzubilden. |
| config/database.js & server.js | Dritter Connection-Pool getAdminPool() analog zu Read/Write hinzugefügt und neuer API Endpoint | Umsetzung von Least Privalages und erlaubt den Export beider Tabellen als CSV |
| keycloak/iot-realm.json | Hinzufügung Admin-user und Test-User | Nötige Identitäten für automatisierten Test und Admin zugang |
| controller/ | | |

## Projektstruktur

Erstellt mit MS-DOS `tree`

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

## Deployment Diagramm

Deployment Diagramm Gesamt

## Services

| Service | Abhängigkeiten | Netzwerk | Erklärung |
|---|---|---|---|
| mariadb / (db) | - | app-network | In mariadb werden die Daten gespeichert;<br/>Die Datenbank kommuniziert nur mit dem Webserver, welcher je nach Nutzer verschieden Zugriffsrechte hat;<br/>Der Start abhängiger Services wird verzögert, bis ein health check absolviert wurde |
| keycloak / (keycloak_web) | - | app-network | Zuständig für Authentifizierung und Authorisierung der Nutzer des Webservers;<br/>Kommuniziert über nginx reverse-proxy mit dem Client und dem Webserver;<br/>Der Start abhängiger Services wird verzögert, bis ein health check absolviert wurde | |
| mosquitto / (mqtt) | - | sensor-network | Broker für die Kommunikation zwischen Pico und Controller;<br/>Kommunikation nach dem Publish/Subscribe-Prinzip;<br/>Auf Port 8883 nach außen sichtbar |
| node.js / (webapp) | db (healhy), keycloak_web (healhty) | app-network | Webserver für das Dashboard;<br/>Image selbstgebaut aus Dockerfile;<br/>Besitzt API-Endpunkte für den Datentransfer;<br/>Übergibt die öffentlichen Dateien an den Client |
| nginx / (owasp/modsecurity-crs:nginx) | webapp | app-network | Schnittstelle für das app-network nach außen;<br/>Reagiert als reverse Proxy auf https-requests und leitet diese an Keycloak und webserver weiter;<br/>Es wird das owasp/modsecurity-crs image verwendet als Schutz vor Cross-Site-Scripting, Sql-Injection und Directory Traversal |
| python / (controller) | mqtt, nginx | sensor-network | Controller für den Pico;<br/>Empfängt über mqtt Sensordaten und gibt diese über nginx an den webserver weiter;<br/>Erstellt aus den Messwerten mittels eines LSTM-Modells eine Messwertprognose und schickt über mqtt Steuersignale an den Pico |

## Beschreibung der Komponenten

### docker-compose.yml

Hier werden die einzelnen Services definiert.

### CA

CA steht für Certificate authority. In diesem Verzeichnis liegen alle verwendeten Zertifikate. Alle verwendeten
Zertifikate sind selbstsigniert.

### configurations

Unter configurations sind alle Dateien abgelegt, die nicht für das Backend benötigt werden.  
Hier liegen das Script für den WLAN-Access-Point und unter pico die Dateien des Pico.

#### pico

Steuert Aktoren über Pins an, liefert Spannungsversorgung für den Sensor und liest Sensordaten aus.
Sendet Sensordaten über MQTT an den MQTT-Broker, liest vom controller gesendete Steuerbefehle über den MQTT-Broker.

#### wlan_ap_setup.py

Mit diesem Skript wird der WLAN-AP aufgesetzt.  
Es wird mit `hostapd` ein Wifi aufgespannt.  
Mit `dnsmasq` wird die Verteilung von IP-Adressen definiert. Das Backend erhält hierbei die statische IP `192.168.4.18`
und den DNS-Namen `local.kleber.data`.
Mittels `nftables` wird eine Firewall erzeugt, die ungewollten traffic automatisch blockiert.

### controller

Empfängt Sensordaten vom MQTT-Broker, validiert und leitet sie per HTTPS an das Backend weiter.
Erstellt mithilfe eines LSTM-Modells Vorhersagen und publiziert Steuerungsbefehle (`COOL`, `HEAT`, `DRY`, `HUM`) an den
Pico.
Authentifiziert sich per Keycloak Client Credentials Flow mit der Rolle `controller-ingest`.

#### `config.py´

Liest alle Betriebsparameter (MQTT, Backend-URL, Keycloak, Schwellenwerte) aus Environment-Variablen und konfiguriert
das Logging.

#### `controller.py`

Einstiegspunkt des Controllers. Prüft beim Start die Keycloak-Authentifizierung und startet den MQTT-Loop.

#### `keycloak_auth.py`

Holt und cached das Keycloak Access-Token per Client Credentials Flow und prüft, ob die Rolle `controller-ingest`
enthalten ist.

#### `mqtt_handler.py`

Baut den MQTT-Client auf und verarbeitet eingehende Nachrichten: Validierung, Weiterleitung ans Backend, LSTM-Vorhersage
und Publish der Steuerungsbefehle auf `actuator/control`.

#### `https_client.py`

Leitet Sensordaten per HTTPS-POST an das Backend weiter, mit API-Key und Bearer-Token im Header.

#### `validation.py`

Prüft eingehende MQTT-Nachrichten auf gültiges JSON, vorhandene Felder und plausible Wertebereiche.

#### `lstm_handler.py`

Lädt das trainierte LSTM-Modell und erstellt Vorhersagen basierend auf den letzten 10 Messwerten.

#### `model_trainer.py`

Trainingsscript für das LSTM-Modell. Liest CSV-Daten, erstellt Sliding-Window-Sequenzen und trainiert das Modell.

#### `data_generation.py`

Generiert synthetische Trainingsdaten (30 Tage, Minutentakt) mit simulierter Thermostat-Logik.

### environment

Enthält die Umgebungsvariablen für die Services. Es war geplant, dass durch eine Änderung an dieser Stelle alle
benötigten Änderungen für alle Services automatisch durchgeführt werden, aber wegen Zeitknappheit konnte dies leider
nicht mehr implementiert werden. Probleme waren besonders die Zertifikate, die durch ein Skript neu generiert werden
müssten.

### keycloak

Hier liegen die Daten des Identitäts- und Zugangsrechte-Verwaltungssystem (IAM).

* Rollen: admin-user, dashboard-user, controller-ingest
* Identitäten: testuser_norole, iotuser01, dashboard-user, admin, service-account-controller-client
* Clients: dashboard-client, controller-client

### mariadb

Hier liegen die Entrypoint Skripte für den Datenbank-Container. In diesen Skripten werden:

* Tabellen für Sensordaten und ein Archiv angelegt
* Ein Job konfiguriert, der einmal täglich alle Messwerte, die älter als eine Woche sind ins Archiv verschiebt
* Nutzerrechte vergibt für einen iot-schreiber-, client-reader- und admin-export-Nutzer

### mosquitto

Hier liegen die Konfigurationsdateien für den mosquitto-broker.  
Unter config liegt die allgemeine Konfiguration, in der Port, Autorisierungsdateien und Zertifikate angegeben werden.  
Bei `log` liegt eine leere log-file, die von mqtt nach dem Start verwendet wird.  
Unter secure liegen die Anmeldedaten für mqtt.

### nginx

Unter nginx liegt die entsprechende Konfigurationsdatei `nginx.conf`.  
In dieser werden Private Key und öffentliches Zertifikat spezifiziert und mehrere reverse-proxys definiert.
Einmal bei https auf /auth zu keycloak.  
Dann bei https auf / zum webserver.  
Und auf http eine Umleitung auf https.

### webapp

Unter webapp liegen alle Dateien für den webserver Container.

#### `config/database.js`

In dieser Datei sind Pools für die jeweiligen Datenbanknutzer definiert.
Hier speziell für den Read-, Write- und Adminuser.

#### public

Dieser Ordner beinhaltet alle Frontend-Elemente für das Anzeigen des Dashboards.

- **css** — Verwendete CSS-Elemente
- **external** — Extern importierte Skripte
- **img** — Bilddateien
- **js** — Verwendete Skripte
- **index.html** — HTML-Element für das Dashboard

#### `service/authentication.js`

Beinhaltet Middleware und Funktion für die Access Token Validierung
Speziell geprüft wird das Vorhandensein des Tokens und die erwarteten Audiences und Rollen.
Darüber hinaus ist der Endpoint für die Authentifizierung des API-Keys für die Datenbankzugriffe definiert.

#### `service/validateSensorPayload.js`

Beinhaltet Funktion um Übertragungsinhalt der Sensoren (Temperatur, Luftfeuchtigkeit, Zeitstempel) zu validieren.
Es wird speziell geprüft:

1. Sind Temperatur und Luftfeuchtigkeit als Zahlen vertreten
2. Ist das Format des Zeitstempels valide
3. Sind Temperatur und Luftfeuchtigkeit innerhalb des definierten Bereiches
4. Ist der Zeitstempel aktuell

Damit werden korrekte Einträge in der Datenbank gewährleistet.

#### `server.js`

Hauptkomponente zum Starten des Webservers. Beinhaltet ebenfalls API für Lese- und Schreibzugriffe auf die
Datenbank.
Gegebene Endpoints:

- **GET /api/status** — Serverstatus abfragen
- **GET /api/sensordata** — Aktuellste Sensordaten erhalten
- **GET /api/sensordata/range** — Sensordaten von einem bestimmten Zeitfenster erhalten
- **GET /api/admin/export** — Aktuelle und archivierte Sensordaten als CSV erhalten
- **POST /api/internal/sensordata** — Sensordaten in Datenbank schreiben

### tests/E2E-tests

End-to-End-Tests, die die gesamte Pipeline vom MQTT-Publish bis zur Datenbank bzw. zum Dashboard abdecken.

#### Test 1: Sensordaten → Datenbank (Happy Path)

    MQTT-Nachricht publizieren → Broker → controller.py → HTTP POST an Backend → Wert in MariaDB prüfen

- Simulierte MQTT-Nachricht `{"temperature": 17.77, "humidity": 44.33}` auf `sensor/data` publishen
- Warten bis der Wert durch die Pipeline fließt
- Prüfen: Ist der Wert im Zeitfenster über `/api/sensordata/range` auffindbar?

#### Test 2: Keycloak AuthN/AuthZ (Token-Flow)

    Controller holt Token → JWT dekodieren → Rolle prüfen → Request mit Bearer Header → Backend akzeptiert

- Client Credentials Flow: Token von Keycloak mit `controller-client` holen
- Prüfen: Hat das JWT die Rolle `controller-ingest` in `realm_access.roles`?
- Prüfen: Akzeptiert `/api/sensordata` einen Request nur mit Bearer Token?

#### Test 3: Unauthentifizierte Requests werden abgelehnt

    Request ohne Auth → nginx → server.js → 401/403 Rejected

- POST ohne jegliche Header → erwartet 401
- POST mit falschem API-Key → erwartet 401
- GET ohne Bearer Token → erwartet 401
- GET mit ungültigem Bearer Token → erwartet 403

#### Test 4: Ungültige Sensordaten werden verworfen

    Ungültige MQTT-Nachricht → Broker → controller.py (verwirft) → kein neuer Eintrag in DB

- 5 verschiedene ungültige Payloads publishen (fehlende Felder, falscher Typ, leerer String, kein JSON, Extremwerte)
- Warten bis Pipeline verarbeitet hätte
- Prüfen: kein neuer Eintrag in der Datenbank seit Testbeginn

#### Test 5: Aktor-Steuerung bei hoher Temperatur

    MQTT "sensor/data" (35°C) → controller.py → LSTM-Modell → MQTT "actuator/control" = "COOL"

- 15 Nachrichten mit `temperature: 35.0` publishen um den LSTM-Buffer zu füllen
- Gleichzeitig auf `actuator/control` Topic subscriben
- Prüfen: Kommt ein `COOL`-Befehl vom Controller zurück?

#### Test 6: TLS-Zertifikatsvalidierung

    HTTPS-Request → nginx (mit CA-Zertifikat validiert)

- Prüfen: CA-Zertifikatsdatei existiert auf dem System
- Prüfen: HTTPS-Verbindung mit korrektem CA-Zertifikat funktioniert
- Prüfen: HTTPS-Verbindung mit falschem Zertifikat wird abgelehnt (SSLError)

#### Test 7: Dashboard-Zugriff (Rollenbasiert)

    User → Keycloak (Login + Token) → nginx → server.js → Rolle prüfen → Zugriff erlauben/verweigern

- 7a: Admin-User (`admin-user` + `dashboard-user`) → 200 auf `/api/sensordata` + 200 auf `/api/admin/export`
- 7b: Normaler User (`dashboard-user`) → 200 auf `/api/sensordata` + 403 auf `/api/admin/export`
- 7c: User ohne Rolle (`testuser_norole`) → 403 auf `/api/sensordata`

## Installation und Inbetriebnahme

### Pi Setup

* Installiere das Raspberry Pi light Image auf beiden Pis
* Lies die MAC-Adresse eines Pis aus; dieser Pi wird später zum Backend

### WLAN AP

* Verbinde den WLAN Pi über ein Netzwerkkabel mit dem Internet
* Stelle eine Verbindung zum Pi via ssh her
* Setze backend_mac_address in Zeile 4 in `/conficuration/wlan_ap_setup.py` auf die MAC-Adresse des Backends
* Führe `sudo apt install hostapd dnsmasq` auf dem Pi aus
* Kopiere jetzt das Skript `wlan_ap_setup.py` auf den Pi und führe es mit root-Rechten aus

### Pi Pico

* Verbinde den Pi Pico über Micro-USB an USB-A/USB-C eines Endgerätes mit Thonny:
    1. BOOTSEL-Taste (weiße Taste auf Pico) gedrückt halten
    2. An Entwicklungs-Endgerät per USB-Kabel anschließen
    3. .uf2-Datei mit der MicroPython-Firmware auf das Laufwerk "RPI-RP2" per Drag und Drop kopieren.
    4. Pico startet neu
* Danach kann der Pi Pico immer wieder eingesteckt und Thonny geöffnet werden
* Der Pi Pico verbindet sich dann automatisch mit Thonny
* main.py auswählen und "Run current script" Button klicken um zu starten
* Bei Spannungsversorgung ohne Datenfluss (zum Beispiel Pico direkt über USB-Kabel an Netzteil) startet main.py
  automatisch

### Gehäuse

* Das Gehäuse besteht aus mehreren Komponenten, die in "documentation/technical drawings" und auch den "documentation/stl-files" gefunden werden können
* Der Peltier-Adapter kann an die Rückseite des Gehäuses eingeschoben werden
* Weitere Komponenten werden verschraubt
* Die stl-files sind 3D-Modell-Dateien, die in einem beliebigen CAD-Programm geöffnet werden können
* Die Technischen Zeichnungen und der Schaltplan sind als SVG-Vektorgrafiken gespeichert
* In CAD-file findet sich die FreeCAD 1.0.2 Projektdatei, welche alle Modelle, Technische Zeichnungen und deren Entwicklungsverlauf aufzeigt
* Bilder des Aufbaus finden sich im Verzeichnis "pico exterior"

### Backend server

* Verbinde dich über ssh mit dem Backend
* Verbinde dich mit `nmtui` mit dem WiFi:
    1. Führe `nmtui` aus
    2. Wähle "Activate a connection"
    3. Wähle das Netzwerk aus und gebe das Passwort ein (Standard: Production, Production-01)
* Klone das Repository auf das Backend
* Installiere Docker Compose
* Zum Starten der Software führe jetzt `sudo docker compose up` im Projektverzeichnis aus

## Bedienung

Die Applikation lässt sich mit `sudo docker compose up/down` starten und beenden.  
Vor dem Start ist sicherzustellen, dass der WLAN-AP Pi hochgefahren und funktionstüchtig ist (z.B. indem geprüft wird,
ob das Backend ´mit dem zugehörigen WLAN verbunden ist).  
Der Pico wird durch Ausführen der `main.py` gestartet.
Nach dem Start kann eine Verbindung zum Netzwerk aufgebaut werden und
unter [https://local.kleber.data](https://local.kleber.data) das Web Dashboard besucht werden.  
Hier folgt eine Anmeldung mit [iotuser01]: [password] oder [admin]: [admin].  
Danach wird das Dashboard angezeigt.
Als Admin besteht außerdem die Möglichkeit alle Sensordaten als CSV-Datei zu exportieren.

## E2E-tests Ergebnisse

Ausgeführt am 10.06.2026 auf dem Raspberry Pi Backend.

| Test | Beschreibung | Ergebnis | Details |
|---|---|---|---|
| Test 1 | Sensor → DB | PASS (4/4) | Temperatur 17.77 in DB gefunden |
| Test 2 | Keycloak Token Flow | PASS (5/5) | Rolle `controller-ingest` vorhanden, Bearer akzeptiert  |
| Test 3 | No Auth Rejected | PASS (4/4) | Alle unautorisierten Requests korrekt abgelehnt |
| Test 4 | Invalid Data Rejected | PASS (3/3) | Kein neuer DB-Eintrag nach 5 ungültigen Nachrichten |
| Test 5 | Actuator Control | PASS (3/3) | 15× `COOL` auf `actuator/control` empfangen |
| Test 6 | TLS Validation | PASS (3/3) | CA-Zertifikat validiert, falsches Zertifikat abgelehnt  |
| Test 7 | Dashboard Access | PASS (8/8) | Admin: voll, User: eingeschränkt, Ohne Rolle: abgelehnt |

**Gesamtergebnis: 7/7 Tests bestanden **

## Fazit

Das Fazit ist unterteilt in die Bewertung der Erfüllung der gegebenen Anforderungen und den persönlichen
Erfahrungsgewinn des Teams.

### Anforderungen

**Funktionale Anforderungen:**

| Nr. | Funktion | Prio | Bewertung |
|-----|---|---|---|
| FA1 | Sensormessung | Must | Erfüllt; Der Pico misst realistische Werte |
| FA2 | Datenübertragung | Must | Erfüllt; getestet in E2E Test 1 |
| FA3 | Automatische Temperatursteuerung | Must | Erfüllt im Rahmen der technischen Möglichkeiten; Temperatur kann erhöht und reduziert werden; Sollwerte sind aber zu weit von Außentemperatur entfernt, um diese zu erreichen; Es entstand das Gefühl, dass zum einen der Temperatursensor nicht immer korrekt misst; Die Luftzirkulation in unserem Gehäuse ist auch nicht optimiert |
| FA4 | Automatische Feuchtigkeitssteuerung | Must | Erfüllt im Rahmen der technischen Möglichkeiten; Luftfeuchtigkeit kann erhöht und reduziert werden; Programm ist mit der Temperaturanpassung stark ausgelastet; Luftfeuchtigkeit wird erst danach reguliert; |
| FA5 | Web-Dashboard (Visualisierung) | Must | Erfüllt; Visualisiert SensorDaten der letzten Woche; Demonstration in Life-Demo |
| FA6 | Manueller Eingriff | Must | Nicht Erfüllt; Ausschließlich automatische Steuerung durch controller; Aus Sicherheitsgründen keine Kommunikation zwischen Pico und Webserver |
| FA7 | Datenspeicherung Kurzzeit | Should | Erfüllt; Sensordaten werden eine Woche in einer Tabelle gespeichert und danach archiviert |
| FA8 | Datenspeicherung Langzeit | Should | Erfüllt; Sensordaten werden nach einer Woche Archiviert; Sind danach im Archiv gespeichert |

Das Produkt erfüllt die wichtigsten funktionalen Anforderungen.
Es fehlt aber der manuelle Eingriff vom Dashboard.
Dieser wäre relevant, wenn das LSTM-Modell es nicht schafft die richtigen Steuersignale an den Pico zu schicken.
Zur Kontrolle wurde in E2E Test 5 geprüft, ob der Controller bei kritisch hohen Temperaturen auf jeden Fall kühlt.
Außerdem gehen wir davon aus, dass der verwendete Temperatursensor defekt ist.
Deswegen ist unklar, inwiefern der gewünschte Temperaturbereich reguliert werden kann.

**Nicht-funktionale Anforderungen:**

| Nr.  | Anforderung | Prio | Bewertung |
|---|---|---|---|
| NFA1 | Sicherheit – Verschlüsselung | Must | Erfüllt; Alle Datentransporte sind durch selbstsignierte Zertifikate gesichert; getestet in E2E Test 6 |
| NFA2 | Authentifizierung & Autorisierung | Must | Erfüllt; Datenabfragen getestet mit E2E Test 7; Kein Zugriff auf Dashboard ohne gültige Anmeldung |
| NFA3 | Netzwerkisolation | Must | Erfüllt; Zugriff von außen durch nftables begrenzt auf mqtt Port 8883 und ssh Port 22 |
| NFA4 | Verfügbarkeit / Zuverlässigkeit | Must | Nicht erfüllt; Aus Sicherheitsgründen keine Kommunikation zwischen Pico und Webserver |
| NFA5 | Kosteneffizienz | Must | Erfüllt; Verwendete Software ist open-source; Zusätzliche Hardware wie das Peltier-Element kostet nur wenige Euro und liegt somit im Budget-Rahmen |
| NFA6 | Wartbarkeit | Should | Erfüllt; Es wurden nur Standardisierte Bibliotheken und Docker Images verwendet |
| NFA7 | Mobilität / WLAN | Must | Erfüllt; Kommunikation über eigenes Production-Wlan |
| NFA8 | Datenschutz (DSGVO) | Should | Erfüllt; Keine kritischen Daten; Sicherheit wird eingehalten |
| NFA9 | Benutzbarkeit | Could  | Nach eigenen Ermessen erfüllt; Das Dashboard wird als Nutzerfreundlich genug eingeschätzt, um von IT-Fremden Personal bedient zu werden |

Die wichtigsten Nicht-Funktionalen Anforderungen sind erfüllt. In Bezug auf die Zuverlässigkeit wurde sich dafür
entschieden aus Sicherheitsgründen auf manuelle Steuerung zu verzichten.

### Erfahrungsgewinn

Das Projekt war nicht nur kompliziert, sondern wies eine hohe Komplexität auf, die durch die unterschiedlichen
Qualifikationen der Entwickler zusätzlich verstärkt wurde. Diese ermöglicht einen großen Erfahrungsgewinn.

#### Fachliche Kompetenz

Im Laufe des Projekts wurden die bestehenden Kompetenzen zu Docker vertieft. Gerade in Bezug auf Sicherheit wurde
Folgendes erlernt:

1. Container in Netzwerken strukturieren, damit sie nicht nach außen sichtbar sind
2. Schnittstellen nach außen gezielt auswählen (Ports, http/https ...)
3. An den Außenschnittstellen Sicherheit gewährleisten (nginx schützt durch OWASP/modsecurity)
4. Validierung von externen Daten nach jeder Kommunikation

Auch in Bezug auf CIA - Confidentiality, Integrity und Availability wurde einiges gelernt:
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

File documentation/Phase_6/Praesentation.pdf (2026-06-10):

# 6. Development of a secure Web Application

# Barnabas Steiner

# Agenda

# 🔑 Keycloak

# 🗄️ MariaDB Least Privilege DB-User

# 🛡️ server.js AuthN/AuthZ für Dashboard & Controller

# ⚙️ controller.py AuthN/AuthZ mit Keycloak

# 🖥️ Web-Dashboard

# 🏁 Fazit
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

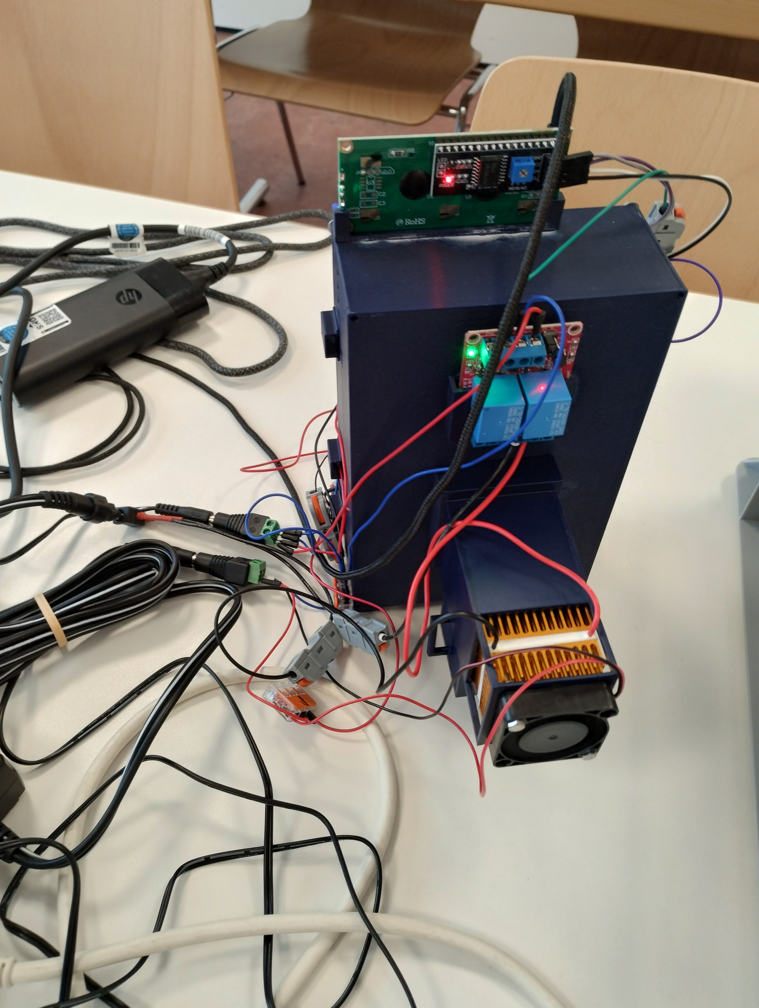
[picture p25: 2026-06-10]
documentation/pico exterior/IMG_20260610_142622528_HDR.jpg

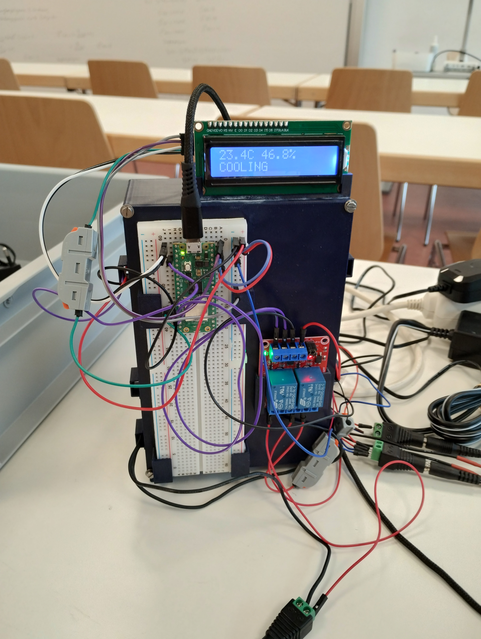
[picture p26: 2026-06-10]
documentation/pico exterior/IMG_20260610_142601154_HDR.jpg

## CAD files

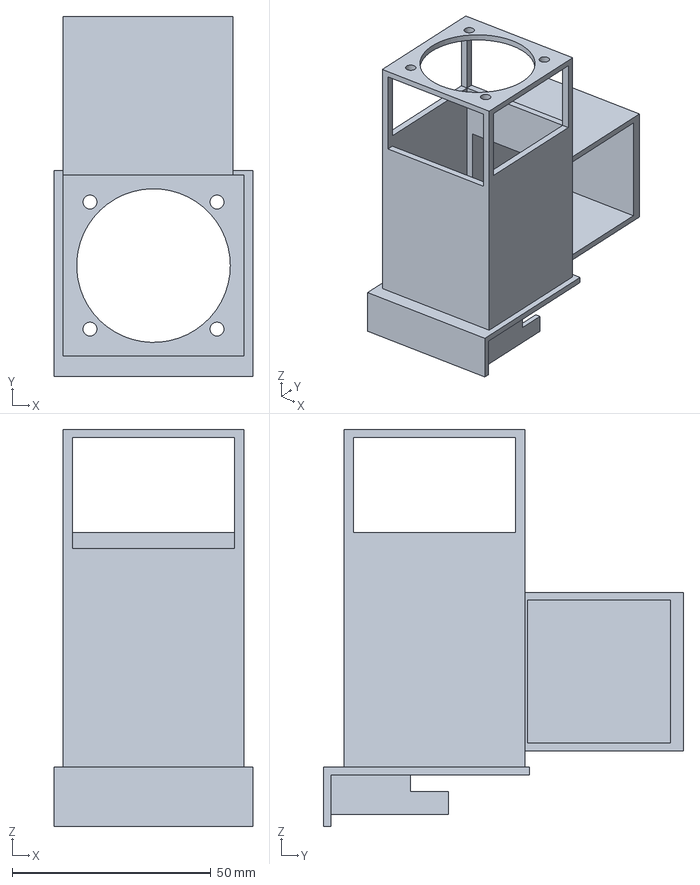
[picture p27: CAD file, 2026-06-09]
documentation/CAD-file/Klebebox-Studium.FCStd
50.0 x 90.8 x 100.0 mm

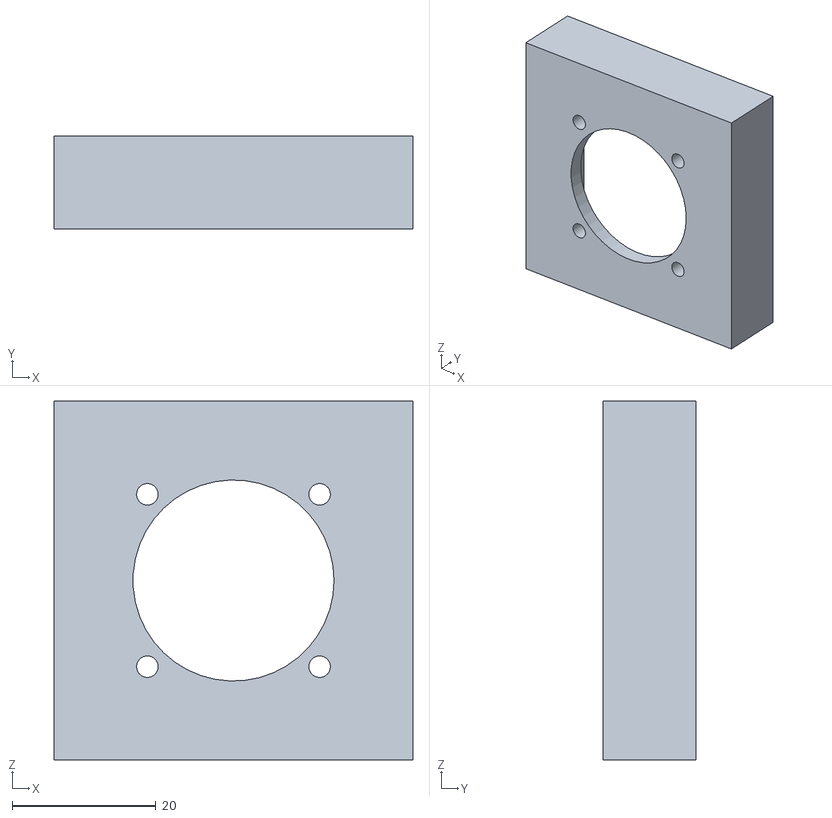
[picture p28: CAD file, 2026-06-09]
documentation/stl-files/Lüfter-Steckadapter.stl
50.0 x 13.0 x 50.0

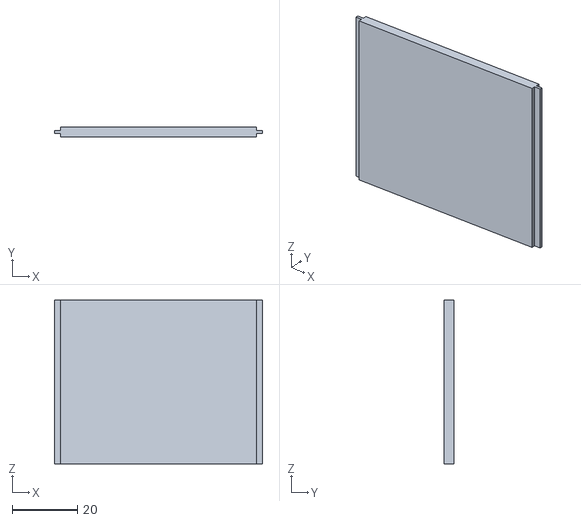
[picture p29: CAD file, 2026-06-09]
documentation/stl-files/Wasserbox-Abdeckung-Geschlossen.stl
63.6 x 3.00 x 50.0

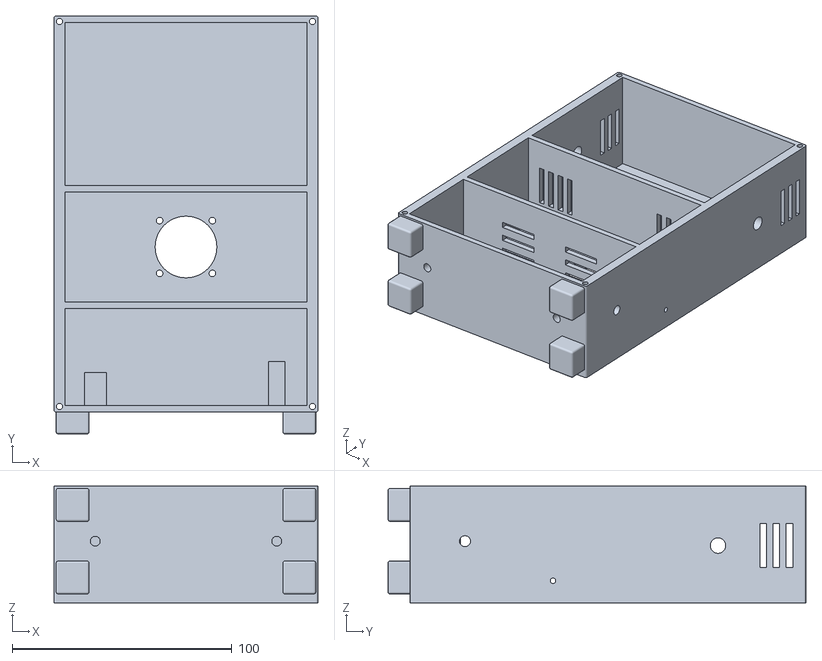
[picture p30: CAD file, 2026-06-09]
documentation/stl-files/Klebebox.stl
120.0 x 190.0 x 53.0

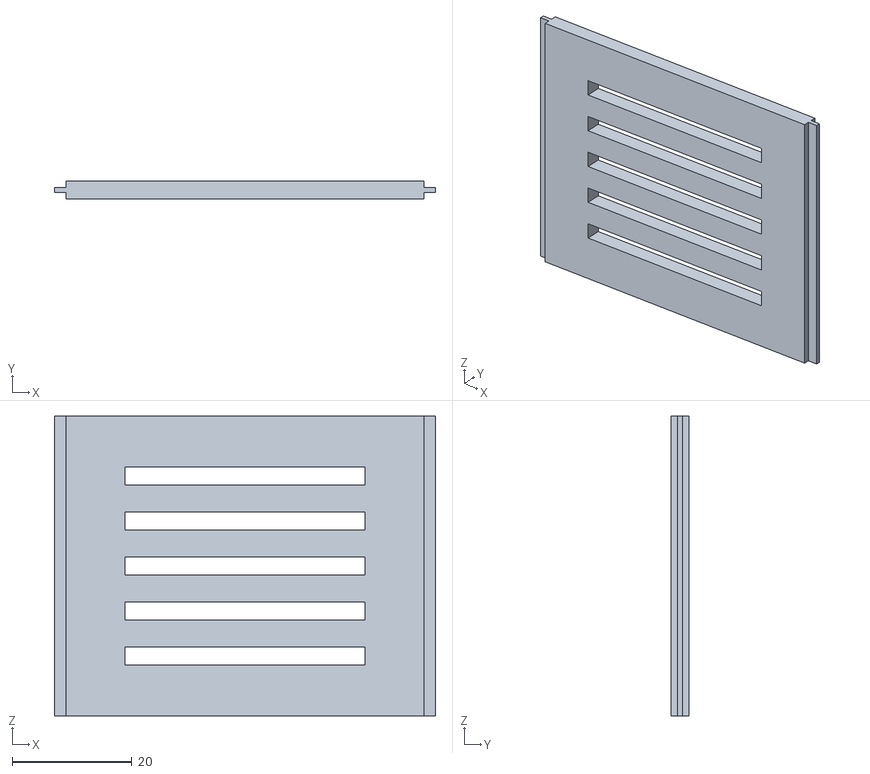
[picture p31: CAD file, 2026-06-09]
documentation/stl-files/Wasserbox-Abdeckung.stl
63.6 x 3.00 x 50.0

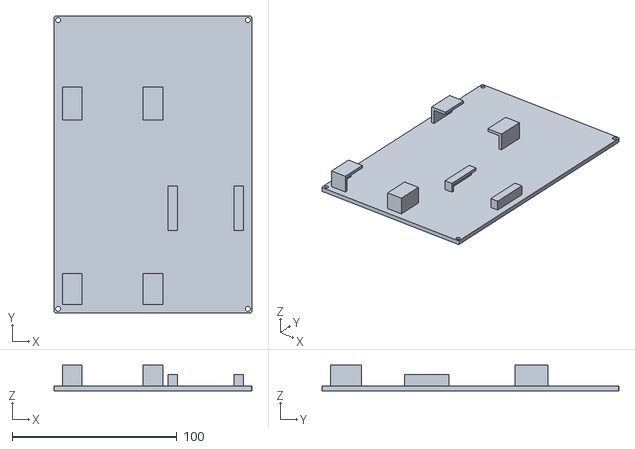
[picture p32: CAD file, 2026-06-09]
documentation/stl-files/Klebebox-Deckel.stl
120.0 x 180.0 x 15.5

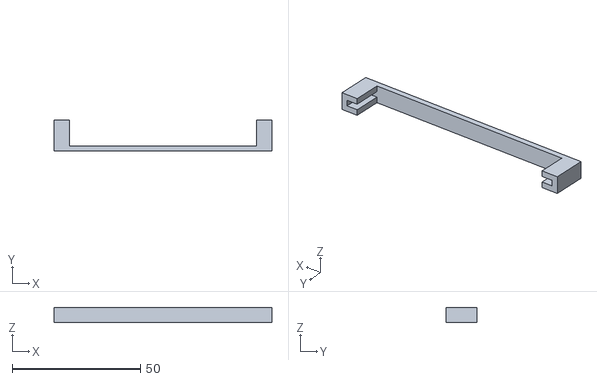
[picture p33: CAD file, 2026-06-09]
documentation/stl-files/LCD-Halterung.stl
85.0 x 12.0 x 6.00

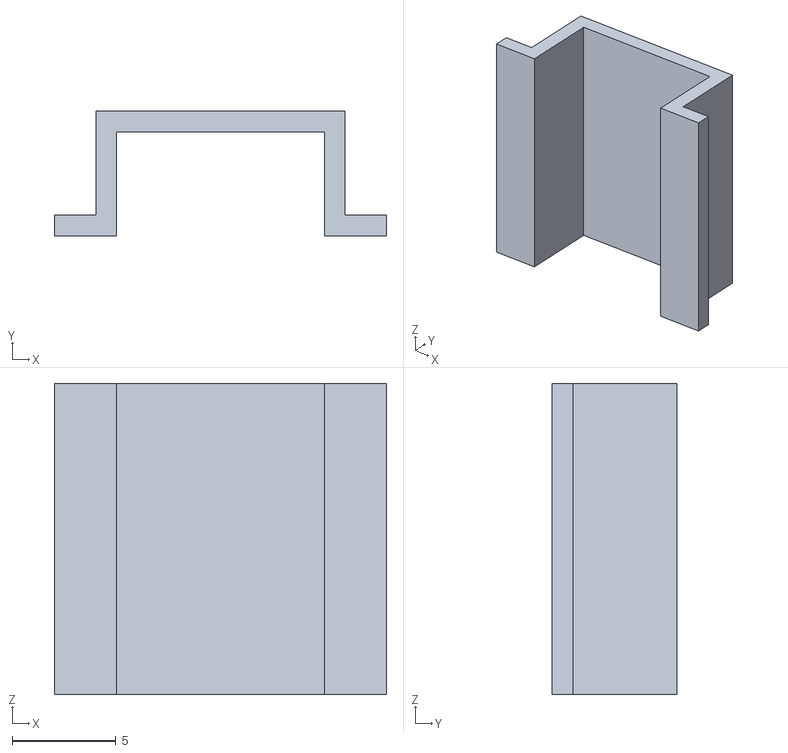
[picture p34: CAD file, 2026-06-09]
documentation/stl-files/Kabelführung.stl
16.0 x 6.00 x 15.0

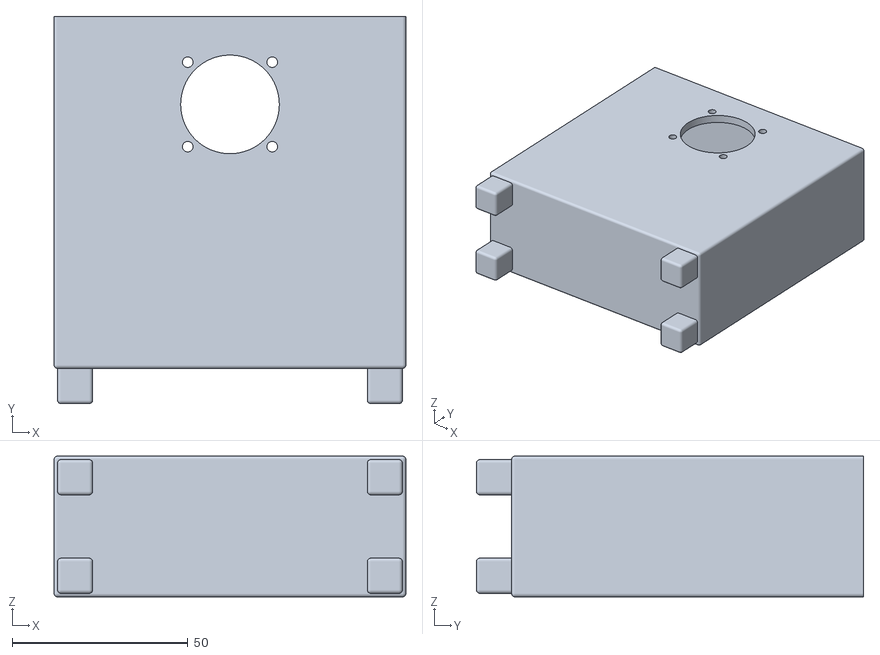
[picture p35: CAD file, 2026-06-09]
documentation/stl-files/Wasserbox.stl
100.0 x 110.0 x 40.0

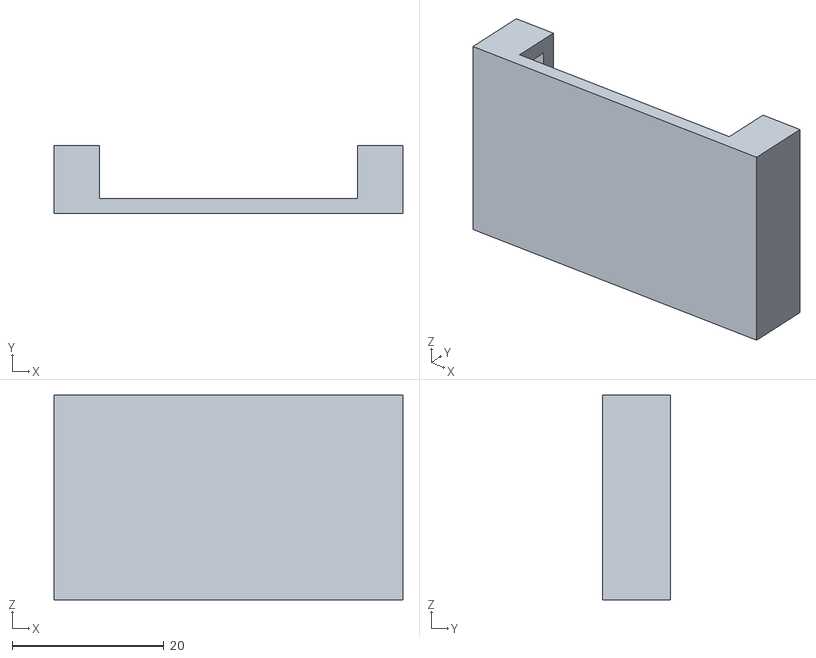
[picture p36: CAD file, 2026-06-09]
documentation/stl-files/Relaishalterung.stl
46.0 x 9.00 x 27.0

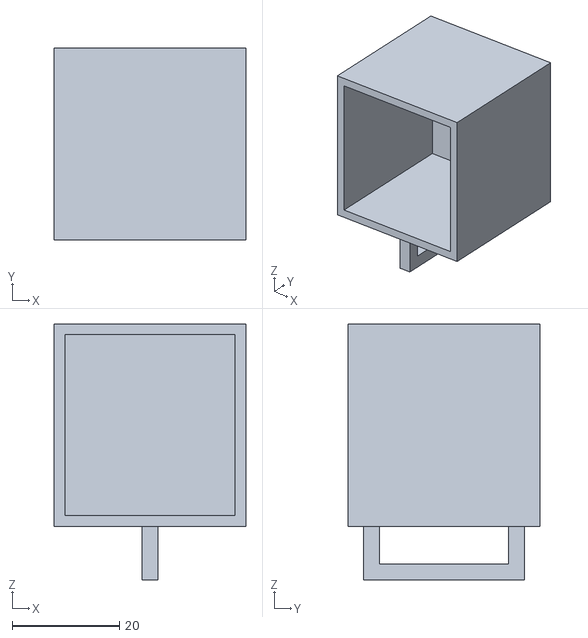
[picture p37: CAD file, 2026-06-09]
documentation/stl-files/Peltier-Adapter-Wasserbox.stl
35.8 x 35.8 x 47.8

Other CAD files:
documentation/stl-files/Peltier-Adapter.stl

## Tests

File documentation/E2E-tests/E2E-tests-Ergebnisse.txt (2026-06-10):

pi@Backend:~/Anwendungsprojekt.Inf/tests/E2E-tests $ ./bin/python3.12 run_all.py

======================================================================

  E2E TEST SUITE  —  All Tests

  2026-06-10 09:48:42

======================================================================

######################################################################

  Running: Test 1: Sensor -> DB (test_1_sensor_to_db.py)

######################################################################

======================================================================

  TEST 1: Sensor Data -> Database (Happy Path)

  2026-06-10 09:48:42

======================================================================

  [PASS]  Dashboard token obtained (user: iotuser01)

  Publishing MQTT message: temp=17.77, hum=44.33

  Topic: sensor/data @ localhost:8883

  [PASS]  MQTT message published

  Waiting 10.0s for data to flow through the pipeline...

  [PASS]  Backend returned sensor data range

         Status 200

  [PASS]  Test temperature found in DB

         Found 17.77 among 1 entries in time window

======================================================================

  RESULT:  4 passed / 0 failed / 0 skipped / 4 total

======================================================================

######################################################################

  Running: Test 2: Keycloak Token Flow (test_2_keycloak_token_flow.py)

######################################################################

======================================================================

  TEST 2: Keycloak Token Flow (Client Credentials)

  2026-06-10 09:49:03

======================================================================

  [PASS]  Token retrieved from Keycloak

         expires_in=300s

  [PASS]  Token is valid JWT format (header.payload.signature)

  [PASS]  Role 'controller-ingest' present in token

         All roles: ['controller-ingest']

  [PASS]  Token not expired

         299s remaining

  [PASS]  Backend validates Bearer token on /api/sensordata

         Status 200

======================================================================

  RESULT:  5 passed / 0 failed / 0 skipped / 5 total

======================================================================

######################################################################

  Running: Test 3: No Auth Rejected (test_3_no_auth_rejected.py)

######################################################################

======================================================================

  TEST 3: Unauthenticated Requests Rejected

  2026-06-10 09:49:04

======================================================================

  [PASS]  POST /api/internal/sensordata without auth -> 401

  [PASS]  POST with wrong API key -> 401

  [PASS]  GET /api/sensordata without Bearer -> 401

  [PASS]  GET with invalid Bearer token -> 403

======================================================================

  RESULT:  4 passed / 0 failed / 0 skipped / 4 total

======================================================================

######################################################################

  Running: Test 4: Invalid Data Rejected (test_4_invalid_data_rejected.py)

######################################################################

======================================================================

  TEST 4: Invalid Sensor Data Rejected

  2026-06-10 09:49:05

======================================================================

  [PASS]  Dashboard token obtained (user: iotuser01)

  [PASS]  Baseline DB entry fetched

         id/timestamp: 130

  -> Published: Temperature out of range (999)

  -> Published: Humidity out of range (-50)

  -> Published: Not valid JSON

  -> Published: Missing humidity field

  -> Published: Non-numeric values

  Waiting 10.0s...

  [PASS]  No new DB entry after invalid messages

         Latest entry still: 130

======================================================================

  RESULT:  3 passed / 0 failed / 0 skipped / 3 total

======================================================================

######################################################################

  Running: Test 5: Actuator Control (test_5_actuator_control.py)

######################################################################

======================================================================

  TEST 5: Actuator Control (High Temperature -> COOL)

  2026-06-10 09:49:52

======================================================================

  [PASS]  Subscribed to 'actuator/control'

  Publishing 15 messages with temp=35.0...

  [PASS]  15 sensor messages published

  Waiting 10.0s for actuator response...

  [PASS]  Received 'COOL' on actuator/control

         All commands received: ['COOL', 'COOL', 'COOL', 'COOL', 'COOL', 'COOL', 'COOL', 'COOL', 'COOL', 'COOL', 'COOL', 'COOL', 'COOL', 'COOL', 'COOL']

======================================================================

  RESULT:  3 passed / 0 failed / 0 skipped / 3 total

======================================================================

######################################################################

  Running: Test 6: TLS Validation (test_6_tls_validation.py)

######################################################################

======================================================================

  TEST 6: TLS Certificate Validation

  2026-06-10 09:50:18

======================================================================

  [PASS]  CA certificate file exists (../../CA/ca.crt)

         Size: 1115 bytes

  [PASS]  HTTPS request with correct CA succeeds

         Status 200

  [PASS]  HTTPS with wrong CA rejected (SSLError raised)

======================================================================

  RESULT:  3 passed / 0 failed / 0 skipped / 3 total

======================================================================

######################################################################

  Running: Test 7: Dashboard Access (test_7_dashboard_access.py)

######################################################################

======================================================================

  TEST 7: Dashboard Access (Role-Based)

  2026-06-10 09:50:29

======================================================================

  --- 7a: Admin user ---

  [PASS]  Login as 'admin'

  [PASS]  Admin GET /api/sensordata -> 200 OK

  [PASS]  Admin GET /api/admin/export -> 200 OK

         Content-Type: text/csv; charset=utf-8

  --- 7b: Normal user ---

  [PASS]  Login as 'iotuser01'

  [PASS]  User GET /api/sensordata -> 200 OK

  [PASS]  User GET /api/admin/export -> 403 Forbidden

  --- 7c: User without 'dashboard-user' role ---

  [PASS]  Login as 'testuser_norole' (no roles)

  [PASS]  No-role user GET /api/sensordata -> 403 Forbidden

         AuthN passed but AuthZ denied (correct behavior)

======================================================================

  RESULT:  8 passed / 0 failed / 0 skipped / 8 total

======================================================================

======================================================================

  COMBINED SUMMARY

======================================================================

  [PASS]  Test 1: Sensor -> DB

  [PASS]  Test 2: Keycloak Token Flow

  [PASS]  Test 3: No Auth Rejected

  [PASS]  Test 4: Invalid Data Rejected

  [PASS]  Test 5: Actuator Control

  [PASS]  Test 6: TLS Validation

  [PASS]  Test 7: Dashboard Access

======================================================================

  7/7 test suites passed, 0 failed

======================================================================

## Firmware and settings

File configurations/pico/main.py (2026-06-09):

from time import sleep, time
from utime import ticks_ms, ticks_diff, sleep_ms
import ujson
import iot_config as iot
import wifi
import states
import control
import mqtt


mqtt.client.set_callback(mqtt.on_message)

#========== Anhang ==========
panel = control.lcd

#0----Interrupt-----
press_time = 0
last_reset = 0

def button_pressed(pin):
    """Reset Button for restarting the pico"""
    global press_time, last_reset
    now   = ticks_ms()
    value = control.button.value()
    
    if value == 0:
        press_time = now
    else:
        if ticks_diff(now, last_reset) < 500:
            return
        if ticks_diff(now, press_time) >= 3000:
            last_reset = now
            sleep_ms(50)
            control.reset()

control.button.irq(
    trigger = control.Pin.IRQ_FALLING | control.Pin.IRQ_RISING,
    handler = button_pressed
)
#1----Interrupt-----
#========== Anhang Ende ==========

"""Connection to WLAN"""
#0----WLAN-Connection-----
try:
    wlan = wifi.connect_wifi()
except OSError as e:
    print("Failed connect wlan: ", e)

#========== Anhang ==========
    panel.clear()
    panel.move_to(0, 0)
    panel.putstr("WLAN Error")
    panel.move_to(0, 1)
    panel.putstr("Reconnecting...")
#========== Anhang Ende ==========

#1----WLAN-Connection-----


sleep(3)


"""Connection to MQTT Broker"""
#0----MQTT-Connection-----
mqtt_connected = False
print("Vor MQTT connect")
try:
    mqtt.client.connect()
    print("Nach MQTT connect")
    mqtt.client.subscribe(iot.MQTT_ACTOR_TOPIC)
    print("subscribed")
    mqtt_connected = True
    print("MQTT verbunden!")
except OSError as e:
    print("Failed connect mqtt: ", e)

#========== Anhang ==========
    panel.clear()
    panel.move_to(0, 0)
    panel.putstr("MQTT Error")
    panel.move_to(0, 1)
    panel.putstr("Reconnecting...")
#========== Anhang Ende ==========

except Exception as e:
    print("MQTT Exception:", e)

#========== Anhang ==========
    panel.clear()
    panel.move_to(0, 0)
    panel.putstr("MQTT Error")
    panel.move_to(0, 1)
    panel.putstr(str(e)[:16])
#========== Anhang Ende ==========

#1----MQTT-Connection-----


#0----LSTM-Preload-Data-----
preload = 0

while preload <= 9:
    """Publishes data to preload the LSTM before the main-loop starts"""
    #0----Sensor-Measuring-----
    control.sensor.measure()
    temp = round(control.sensor.temperature(), 1)
    hum  = round(control.sensor.humidity(), 1)
    #1----Sensor-Measuring-----


    #0----MQTT-Message-----
    payload = ujson.dumps({
      "temperature": temp,
      "humidity"   : hum
    })

    if mqtt_connected:
        mqtt.client.publish(iot.MQTT_SENSOR_TOPIC, payload)
        print("Published Preload Data")
    #1----MQTT-Message-----
    
    preload = preload + 1
    
    #========== Anhang ==========
    #0----Preload-Display-----
    panel.clear()
    panel.move_to(0, 0)
    panel.putstr("{:.1f}C".format(temp))
    panel.putstr(" ")
    panel.putstr("{:.1f}%".format(hum))
    panel.move_to(0, 1)
    panel.putstr("Preloading Data")
    #1----Preload-Display-----
    #========== Anhang Ende ==========
        
    sleep(5)
#1----LSTM-Preload-Data-----


while True:
    """Main-Loop"""
    try:
        #0----Sensor-Measuring-----
        control.sensor.measure()
        temp = round(control.sensor.temperature(), 1)
        hum  = round(control.sensor.humidity(), 1)
        #1----Sensor-Measuring-----


        #0----MQTT-Message-----
        payload = ujson.dumps({
          "temperature": temp,
          "humidity"   : hum
        })

        if mqtt_connected:
            mqtt.client.publish(iot.MQTT_SENSOR_TOPIC, payload)
            print("Published")

        wait_start = ticks_ms()
        while ticks_diff(ticks_ms(), wait_start) < 59000:
            if mqtt_connected:
                mqtt.client.check_msg()
                if mqtt.process_last():
                    
                    #========== Anhang ==========
                    #0----Value-Display-----
                    panel.clear()
                    panel.move_to(0, 0)
                    panel.putstr("{:.1f}C".format(temp))
                    panel.putstr(" ")
                    panel.putstr("{:.1f}%".format(hum))
                    panel.move_to(0, 1)
                    panel.putstr(str(states.current_state))
                    #1----Value-Display-----
                    #========== Anhang Ende ==========
            
            
            sleep_ms(1000)
        #1----MQTT-Message-----

    #========== Anhang ==========
        #states.lcd.clear()
        #states.scroll_text("Das ist ein sehr langer Text um den Scroll Text zu testen", zeile=0)

    #0----Sensor-Error-----
    except OSError as e:
        print("Failed to read sensor: ", e)
        panel.clear()
        panel.move_to(0, 0)
        panel.putstr("Sensor Error")
        panel.move_to(0, 1)
        panel.putstr("Can't read")
    #1----Sensor-Error-----
    #========== Anhang Ende ==========



# https://projects.raspberrypi.org/en/projects/getting-started-with-the-pico/3
# Zugriff: 18.04.2026
# Pico W firmware

# https://pip-assets.raspberrypi.com/categories/686-raspberry-pi-pico-w/documents/RP-008312-DS-1-pico-w-datasheet.pdf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
# Zugriff: 18.04.2026
# Pico W datasheet

# https://docs.micropython.org/en/latest/rp2/quickref.html
# Zugriff: 24.04.2026
# RP2 code reference

# https://github.com/micropython/micropython-lib/blob/master/micropython/umqtt.simple/example_sub.py
# Zugriff: 18.05.2026
# umqtt reference

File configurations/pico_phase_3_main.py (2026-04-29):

from picozero import pico_led
from machine import Pin
from time import sleep, time
import dht
import network
import urequests as requests

"""WLAN Parameter für den Aufbau einer Verbindung"""
SSID = "Production" # Production
PASSWORD = "Production-01" # Production-01

"""Backend-Proxy
BACKEND_PROXY_URL = "http://192.168.50.20:5000/weather"

REST API für Friedrichshafen
API_URL = (
    "https://api.open-meteo.com/v1/forecast"
    "?latitude=47.65&longitude=9.48&current_weather=true"
)
"""

"""Inputs / Outputs für Sensoren / Aktoren"""
sensor = dht.DHT22(Pin(2, Pin.IN, Pin.PULL_UP))
radiator = Pin(12, Pin.OUT)
fan = Pin(13, Pin.OUT)

"""Pico LED zeigt an, ob der Pico W läuft"""
pico_led.on()

"""Zustände für Temperatur- und Luftfeuchtigkeit"""
STATE_HIGH_TEMP_LOW_HUM = 0
STATE_LOW_TEMP_LOW_HUM  = 1
STATE_HIGH_TEMP_HIGH_HUM = 2
STATE_LOW_TEMP_HIGH_HUM  = 3

current_state = None

def connect_wifi():
    """Verbindung zum WLAN"""
    wlan = network.WLAN(network.STA_IF) # Client-Modus, verbindet sich mit einem Router
    wlan.active(True)
    wlan.connect(SSID, PASSWORD)

    print("Verbinde mit WLAN...")
    while not wlan.isconnected():
        sleep(1)
        print("...")

    print("Verbunden! IP:", wlan.ifconfig()[0])
    return wlan

"""
def fetch_outside_temperature():
    try:
        print("Hole Außentemperatur von Open-Meteo...")
        r = requests.get(API_URL)
        data = r.json()
        r.close()
        temp = data["current_weather"]["temperature"]
        print("Außentemperatur Friedrichshafen:", temp, "°C")
        return temp
    except Exception as e:
        print("Fehler bei API:", e)
        return None


def get_blink_interval(temp):
    if temp is None:
        return 1.0
    if temp < 10:
        return 2.0
    elif temp <= 25:
        return 1.0
    else:
        return 0.3
"""

def apply_state(state):
    """Anwendung State-Machine"""
    global current_state

    if state == STATE_HIGH_TEMP_LOW_HUM:
        radiator.off()
        fan.on()
        print("STATE: Temp HIGH, Hum LOW")

    elif state == STATE_LOW_TEMP_LOW_HUM:
        radiator.on()
        fan.on()
        print("STATE: Temp LOW, Hum LOW")

    elif state == STATE_HIGH_TEMP_HIGH_HUM:
        radiator.off()
        fan.off()
        print("STATE: Temp HIGH, Hum HIGH")

    elif state == STATE_LOW_TEMP_HIGH_HUM:
        radiator.on()
        fan.off()
        print("STATE: Temp LOW, Hum HIGH")

    current_state = state


def determine_state(temp, hum):
    """State-Machine"""
    if temp > 20.5 and hum < 52.0:
        return STATE_HIGH_TEMP_LOW_HUM

    if temp < 19.5 and hum < 52.0:
        return STATE_LOW_TEMP_LOW_HUM

    if temp > 20.5 and hum > 58.0:
        return STATE_HIGH_TEMP_HIGH_HUM

    if temp < 19.5 and hum > 58.0:
        return STATE_LOW_TEMP_HIGH_HUM

    return current_state

# wlan = connect_wifi() # Wlan verbinden

"""
outside_temp = fetch_outside_temperature()
blink_interval = get_blink_interval(outside_temp)
next_api_call = time() + 600  # alle 10 Minuten
"""

while True:
    """Haupt-Loop"""
    """
    pico_led.on()
    sleep(blink_interval / 2)
    pico_led.off()
    sleep(blink_interval / 2)

    if time() >= next_api_call:
        outside_temp = fetch_outside_temperature()
        blink_interval = get_blink_interval(outside_temp)
        next_api_call = time() + 600
    """
   
    try:
        sensor.measure()
        temp = sensor.temperature()
        hum = sensor.humidity()

        print("Temperature: {:.1f}°C   Humidity: {:.1f}%".format(temp, hum))

        new_state = determine_state(temp, hum)

        if new_state != current_state:
            apply_state(new_state)

    except OSError:
        print("Failed to read sensor:", e)

    sleep(2)


# https://projects.raspberrypi.org/en/projects/getting-started-with-the-pico/3
# Zugriff: 18.04.2026
# Pico W firmware

# https://pip-assets.raspberrypi.com/categories/686-raspberry-pi-pico-w/documents/RP-008312-DS-1-pico-w-datasheet.pdf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
# Zugriff: 18.04.2026
# Pico W datasheet

# https://docs.micropython.org/en/latest/rp2/quickref.html
# Zugriff: 24.04.2026
# RP2 code reference

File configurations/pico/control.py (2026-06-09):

from picozero import pico_led
from machine import Pin, I2C, reset
from pico_i2c_lcd import I2cLcd
from time import sleep
import dht


"""Initialization Input/Output"""
#0----Initialization-----
sensor 	 = dht.DHT22(Pin(2, Pin.IN, Pin.PULL_UP))
radiator = Pin(12, Pin.OUT)
fan 	 = Pin(13, Pin.OUT)

#========== Anhang ==========
peltier = Pin(11, Pin.OUT)
button 	 = Pin(14, Pin.IN, Pin.PULL_UP) # Reset Button
i2c 	 = I2C(0, sda=Pin(0), scl=Pin(1), freq=400000)
lcd 	 = I2cLcd(i2c, 0x27, 2, 16)
#========== Anhang Ende ==========

#1----Initialization-----

pico_led.on()

#========== Anhang ==========
def scroll_text(text, zeile=0):
    """Scrolls the Text on the LCD-Display from right to left"""
    padded = " " * 16 + text + " " * 16
    prev   = ""
    for i in range(len(padded) - 15):
        current = padded[i:i+16]
        for j in range(16):
            if j >= len(prev) or current[j] != prev[j]:
                lcd.move_to(j, zeile)
                lcd.putstr(current[j])
        prev = current
        sleep(0.2)
#========== Anhang Ende ==========

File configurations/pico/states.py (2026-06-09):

import control


"""State Variables"""
#0----States-----
TEMP_TOO_LOW  = 0
TEMP_OK       = 1
TEMP_TOO_HIGH = 2

HUM_TOO_LOW   = 3
HUM_OK        = 4
HUM_TOO_HIGH  = 5

current_state = None

TEMP_MIN = 19.5
TEMP_MAX = 20.5
HUM_MIN  = 42.0
HUM_MAX  = 53.0
#1----States-----


#0----Apply State-----
def apply_state(temp_state, hum_state):
    """Regulates temperature first, then humidity"""

    global current_state

    if temp_state == TEMP_TOO_HIGH:
        control.radiator.off()
        control.fan.on()
        control.peltier.on()
        print("STATE: Temp HIGH → Kühlen")
        current_state = "COOLING"
        return

    if temp_state == TEMP_TOO_LOW:
        control.radiator.on()
        control.fan.off()
        control.peltier.off()
        print("STATE: Temp LOW → Heizen")
        current_state = "HEATING"
        return

    if hum_state == HUM_TOO_HIGH:
        control.radiator.on()
        control.fan.off()
        control.peltier.off()
        print("STATE: Hum HIGH → Trocknen (Heizen)")
        current_state = "DRYING"
        return

    if hum_state == HUM_TOO_LOW:
        control.radiator.off()
        control.fan.on()
        control.peltier.off()
        print("STATE: Hum LOW → Befeuchten (Kühlen)")
        current_state = "HUMIDIFYING"
        return

    control.radiator.off()
    control.fan.off()
    control.peltier.off()
    print("STATE: Alles OK → Alles AUS")
    current_state = "OK"
#1----Apply State-----

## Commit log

2026-04-24 Fix wrong Firewall options
    [wlan_ap_setup.py]
2026-04-27 Raspberry Pi Pico W Wlan-Integration
2026-04-27 Phase 2 pico integration
2026-04-29 Phase 3 Pico (partly done)
2026-04-30 separated pico files
2026-05-07 CA generated for CA, MQTT and Pico fix
2026-05-07 configured server.js for sensor post requests
2026-05-07 Pico files update
2026-05-11 controller attempt mounting certificate in compose as volume
2026-05-12 Enhance validation with error logging
    Added error logging for invalid temperature, humidity, and timestamp checks.
2026-05-13 Updated pico files
2026-05-17 Update controller.py with forecast function, publish auf actuator/control, warmstart
2026-05-18 Switch nginx to http reverse proxy
2026-05-18 Updated pico files, docstrings + mqtt sub + actors
2026-05-18 Add from pico missing in sensor-net/mqqt_handler and missing humidity low and high in sensor-net/config.py
2026-05-18 Wlan_AP allows pico connection to mqtt broker
    [wlan_ap_setup.py]
2026-05-20 Lstm training implementation
    [Messdaten.csv]
2026-05-20 Phase 5 final pico files
2026-05-20 quickfix pico action is now evaluated by halved sum of lstm-prediction and measurement
2026-05-20 controller uses temperature measurement before enough data for prediction is collected
2026-05-22 webapp print pool for debug
2026-05-22 Revert "webapp print pool for debug"
    This reverts commit 98302238677a0b510404cdf0a818f7d2994162e5.
2026-05-22 controller send temperature instead of prognosis to training_data
2026-05-27 keycloak docker compose removed start switches
2026-05-29 Move environment variables to environment directory
    [Messdaten.csv]
2026-06-02 LSTM model better approximation and publishes correct action for pico
2026-06-02 LSTM first retrain
    [Messdaten.csv]
2026-06-02 LSTM second retrain with different data
    [Messdaten2.csv]
2026-06-02 LSTM training #3
    [Messdaten.csv, weather_data.csv]
2026-06-07 chart x-axis refactor
2026-06-07 broken chart x-axis fix
2026-06-08 augen zu und durch
2026-06-09 3 AM push documentation
    [Kabelführung.stl, Klebebox-Deckel.stl, Klebebox.stl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]
2026-06-09 Final pico file changes
2026-06-09 mechanical drawings finished + pico files finished
    [Klebebox-Studium.FCStd]
2026-06-09 Readme pico + changes
2026-06-09 pico part in doku.md
2026-06-09 doku pico parts + Hilfsmittel
2026-06-10 doku.md Phase 3 complete (Schau nicht auf die Uhrzeit des Push)
2026-06-10 export button and roles
2026-06-10 doku fachliche Kompetenzen und Gemini Hilfsmittel
2026-06-10 doku erklärung Temperatur
2026-06-10 Pico Exterior
2026-06-10 Add: Eigenständigkeitserklärung.pdf
